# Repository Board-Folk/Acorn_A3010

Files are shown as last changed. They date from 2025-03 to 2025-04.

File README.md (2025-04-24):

# Reproduction A3010 PCB #

This repository contains the schematics and PCB layout for a reproduction
of the Acorn A3010 computer PCB - specifically the 194,003 issue 1.

Other variations of the board exist and may be included as separate designs
at a future date.

Where possible the board matches the location of components and routing of
traces.

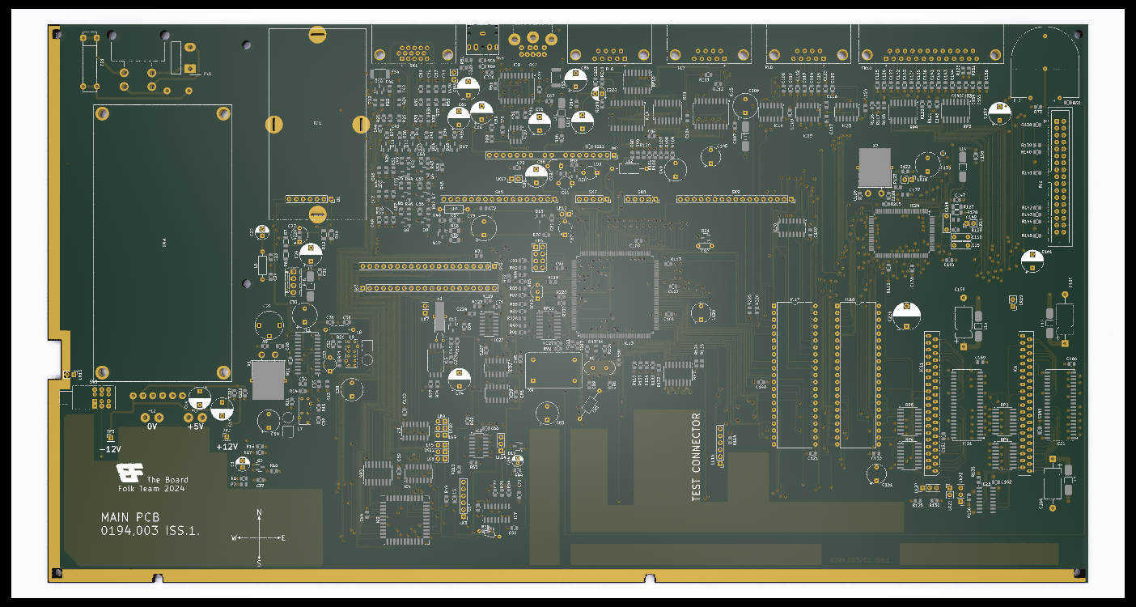
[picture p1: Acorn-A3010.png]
Render of PCB front


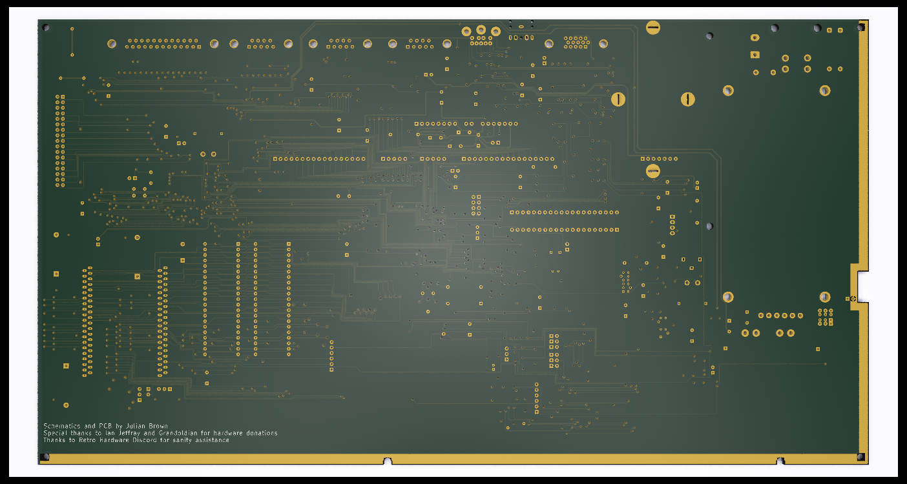
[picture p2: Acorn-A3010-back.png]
Render of PCB rear


## Progress ##

The schematics and PCB design are both complete. An initial fabrication run has
been completed and in the process of being tested. The first board is populated
and while it appears to be working over the post port, there is no apparent video
output

### Changes from first test build ###

The AC inputs to the Mean Well psu were reversed. This should not technically
Be a problem for the psi so can be considered cosmetic.

Footprint pad sizes have been enlarged for the LQFP and J-leg components to aid
With hand assembly.

### Known issues ###

The specified fuse rating for the AC input is inadequate for the Mean Well psu.
The initial power-up produces a spike in current that blows the fuse immediately,
it may prove more appropriate to remove the fuse and add protection to the outputs 

## Factory Fixes ##

The original boards include a number of fixes, these have been incorporated
into the design where possible.

## Variations From Standard ##

In a few places the board is non-standard to allow the use of modern, available
components, most notably the power supply area of the board. Instead of the 
original circuits the board is designed to accept a Mean Well unit that is 
both lighter and more efficient.

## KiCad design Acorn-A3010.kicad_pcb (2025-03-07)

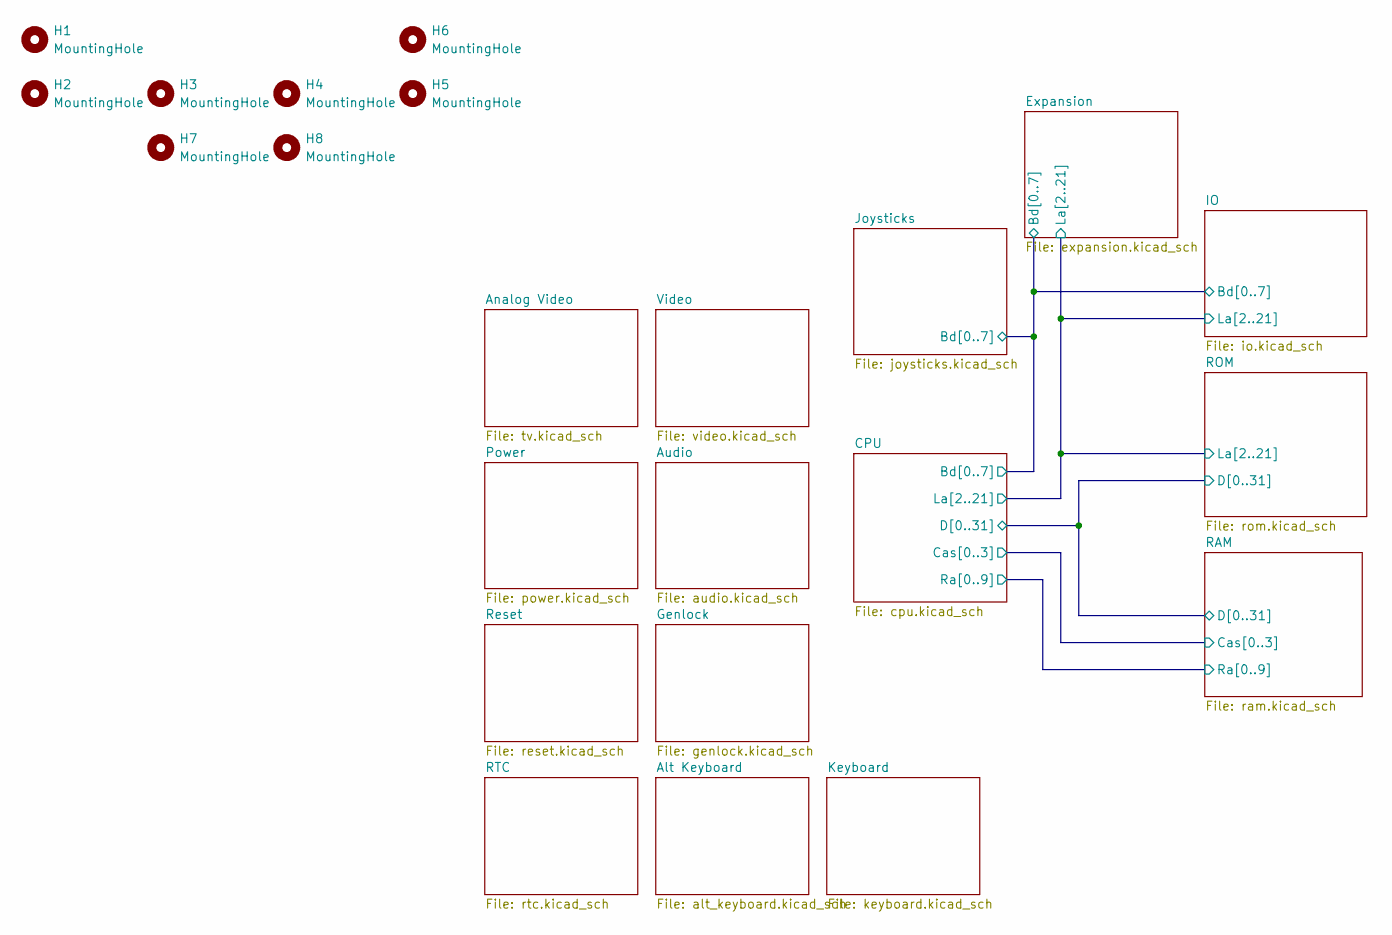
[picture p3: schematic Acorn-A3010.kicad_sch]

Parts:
H1, H2, H3, H4, H5, H6, H7, H8: MountingHole; MountingHole_3.2mm_M3

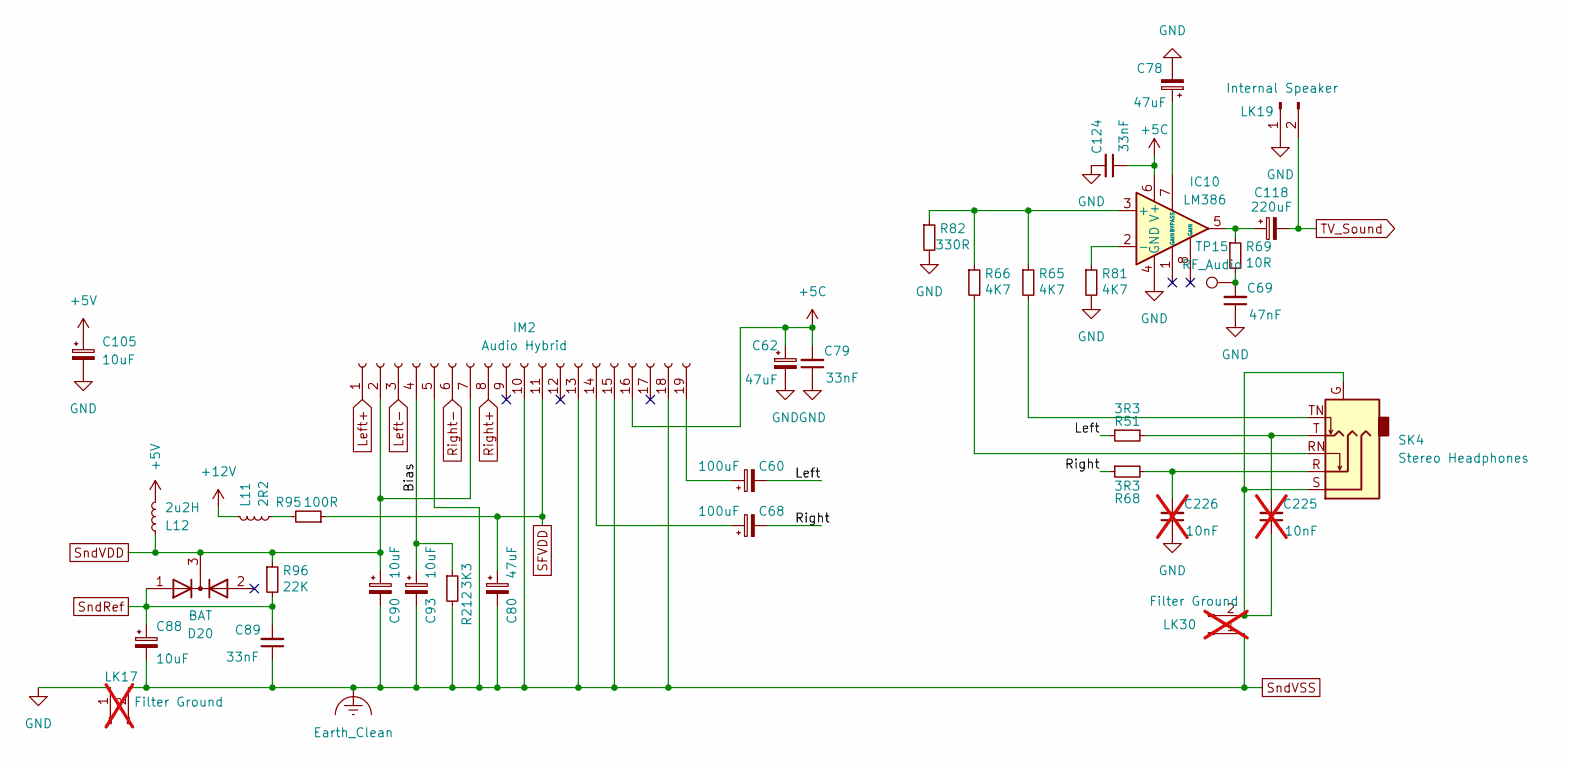
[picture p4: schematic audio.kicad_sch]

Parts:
C60, C68: 100uF; CP_Radial_D8.0mm_P5.00mm
C62, C78, C80: 47uF; CP_Radial_D8.0mm_P5.00mm
C69: 47nF; C_0805_2012Metric
C79, C89, C124: 33nF; C_0805_2012Metric
C88, C90, C93: 10uF; CP_Radial_Tantal_D4.5mm_P5.00mm
C105: 10uF; CP_Radial_Tantal_D7.0mm_P5.00mm
C118: 220uF; CP_Radial_D8.0mm_P5.00mm
C225, C226: 10nF; C_0805_2012Metric; not fitted
D20: BAT; SOT-23-3
IC10: LM386; SOIC-8_3.9x4.9mm_P1.27mm
IM2: Audio Hybrid; Audio_Hybrid
L11: 2R2; L_Acorn_8x3mm
L12: 2u2H; L_Axial_L7.0mm_D3.3mm_P12.70mm_Horizontal_Fastron_MICC
LK17, LK30: Filter Ground; PinHeader_1x02_P2.54mm_Vertical; not fitted
LK19: Internal Speaker; PinHeader_1x02_P2.54mm_Vertical
R51, R68: 3R3; R_0805_2012Metric
R65, R66, R81: 4K7; R_0805_2012Metric
R69: 10R; R_0805_2012Metric
R82: 330R; R_0805_2012Metric
R95: 100R; R_0805_2012Metric
R96: 22K; R_0805_2012Metric
R212: 3K3; R_0805_2012Metric
SK4: Stereo Headphones; Jack_3.5mm_CUI_SJ1-3525N_Horizontal
TP15: RF_Audio; TestPoint_Pad_D1.0mm

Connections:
+5C: C62.1, C79.2, C124.1, IC10.6 (V+), IM2.16; also elsewhere on the board
+5V: C105.1, L12.2; also elsewhere on the board
+12V: L11.1; also elsewhere on the board
/Audio/Bias: C93.1, IM2.4, R212.1
/Audio/Left: C60.2, R51.1
/Audio/Right: C68.2, R68.1
GND: C62.2, C69.1, C78.2, C79.1, C105.2, C124.2, C226.1, IC10.4 (GND), LK17.1, LK19.1, R81.2, R82.2; also elsewhere on the board
Left+: IM2.1; also elsewhere on the board
Left-: IM2.3; also elsewhere on the board
unnamed: C69.2, R69.2, TP15.1
unnamed: C118.1, IC10.5, R69.1
unnamed: C225.2, R51.2, SK4.T
unnamed: C226.2, R68.2, SK4.R
unnamed: IC10.3 (+), R65.1, R66.1, R82.1
unnamed: IC10.2 (-), R81.1
unnamed: C78.1, IC10.7 (BYPASS)
unnamed: C68.1, IM2.14
unnamed: C60.1, IM2.19
unnamed: L11.2, R95.2
unnamed: C225.1, LK30.2, SK4.G, SK4.S
unnamed: R65.2, SK4.TN
unnamed: R66.2, SK4.RN
Right+: IM2.8; also elsewhere on the board
Right-: IM2.6; also elsewhere on the board
SFVDD: C80.1, IM2.11, R95.1
SndRef: C88.1, C89.2, D20.1 (A), R96.2; also elsewhere on the board
SndVDD: C90.1, D20.3 (K), IM2.2, IM2.7, L12.1, R96.1; also elsewhere on the board
SndVSS: C80.2, C88.2, C89.1, C90.2, C93.2, IM2.5, IM2.10, IM2.13, IM2.15, IM2.18, LK17.2, LK30.1, R212.2; also elsewhere on the board
TV_Sound: C118.2, LK19.2; also elsewhere on the board

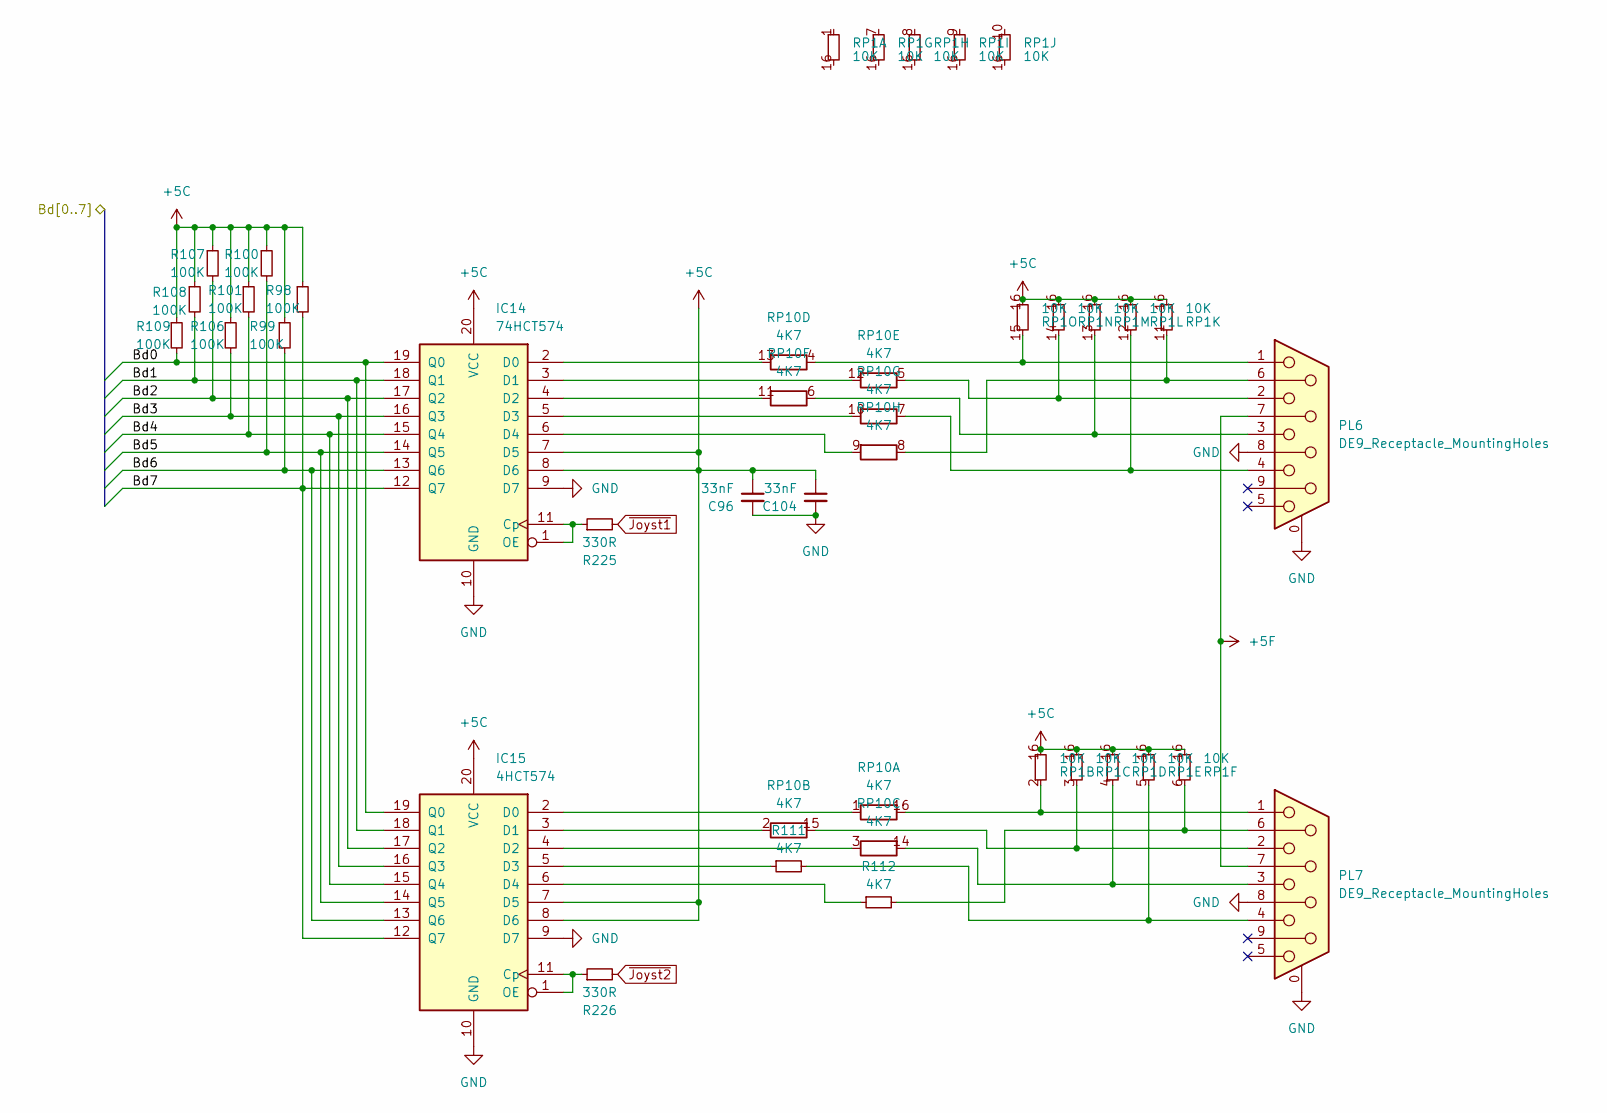
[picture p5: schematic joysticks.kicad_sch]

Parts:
C96, C104: 33nF; C_0805_2012Metric
IC14: 74HCT574; SOIC-20W_7.5x12.8mm_P1.27mm
IC15: 4HCT574; SOIC-20W_7.5x12.8mm_P1.27mm
PL6, PL7: DE9_Receptacle_MountingHoles; DSUB-9_Male_Horizontal_P2.77x2.84mm_EdgePinOffset9.90mm_Hou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
R98, R99, R100, R101, R106, R107, R108, R109: 100K; R_0805_2012Metric
R111, R112: 4K7; R_0805_2012Metric
R225, R226: 330R; R_0805_2012Metric
RP1: 10K; SOIC-16W_5.3x10.2mm_P1.27mm
RP10: 4K7; SOIC-16W_5.3x10.2mm_P1.27mm

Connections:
+5C: C96.1, C104.1, IC14.7 (D5), IC14.8 (D6), IC14.20 (VCC), IC15.7 (D5), IC15.8 (D6), IC15.20 (VCC), R98.1, R99.1, R100.1, R101.1, R106.1, R107.1, R108.1, R109.1, RP1.16; also elsewhere on the board
+5F: PL6.7, PL7.7; also elsewhere on the board
/CPU/Bd0: IC14.19 (Q0), IC15.19 (Q0), R109.2; also elsewhere on the board
/CPU/Bd1: IC14.18 (Q1), IC15.18 (Q1), R108.2; also elsewhere on the board
/CPU/Bd2: IC14.17 (Q2), IC15.17 (Q2), R107.2; also elsewhere on the board
/CPU/Bd3: IC14.16 (Q3), IC15.16 (Q3), R106.2; also elsewhere on the board
/CPU/Bd4: IC14.15 (Q4), IC15.15 (Q4), R101.2; also elsewhere on the board
/CPU/Bd5: IC14.14 (Q5), IC15.14 (Q5), R100.2; also elsewhere on the board
/CPU/Bd6: IC14.13 (Q6), IC15.13 (Q6), R99.2; also elsewhere on the board
/CPU/Bd7: IC14.12 (Q7), IC15.12 (Q7), R98.2; also elsewhere on the board
GND: C96.2, C104.2, IC14.9 (D7), IC14.10 (GND), IC15.9 (D7), IC15.10 (GND), PL6.0 (PAD), PL6.8, PL7.0 (PAD), PL7.8; also elsewhere on the board
unnamed: IC14.1 (OE), IC14.11 (Cp), R225.1
unnamed: IC14.2 (D0), RP10.13 (R4.2)
unnamed: IC14.3 (D1), RP10.12 (R5.2)
unnamed: IC14.4 (D2), RP10.11 (R6.2)
unnamed: IC14.5 (D3), RP10.10 (R7.2)
unnamed: IC14.6 (D4), RP10.9 (R8.2)
unnamed: IC15.1 (OE), IC15.11 (Cp), R226.1
unnamed: IC15.2 (D0), RP10.1 (R1.1)
unnamed: IC15.3 (D1), RP10.2 (R2.1)
unnamed: IC15.4 (D2), RP10.3 (R3.1)
unnamed: IC15.5 (D3), R111.1
unnamed: IC15.6 (D4), R112.1
unnamed: PL7.4, R111.2, RP1.5
unnamed: PL7.6, R112.2, RP1.6
unnamed: PL7.1, RP1.2, RP10.16 (R1.2)
unnamed: PL7.2, RP1.3, RP10.15 (R2.2)
unnamed: PL7.3, RP1.4, RP10.14 (R3.2)
unnamed: PL6.1, RP1.15, RP10.4 (R4.1)
unnamed: PL6.2, RP1.14, RP10.5 (R5.1)
unnamed: PL6.3, RP1.13, RP10.6 (R6.1)
unnamed: PL6.4, RP1.12, RP10.7 (R7.1)
unnamed: PL6.6, RP1.11, RP10.8 (R8.1)
~Joyst1: R225.2; also elsewhere on the board
~Joyst2: R226.2; also elsewhere on the board

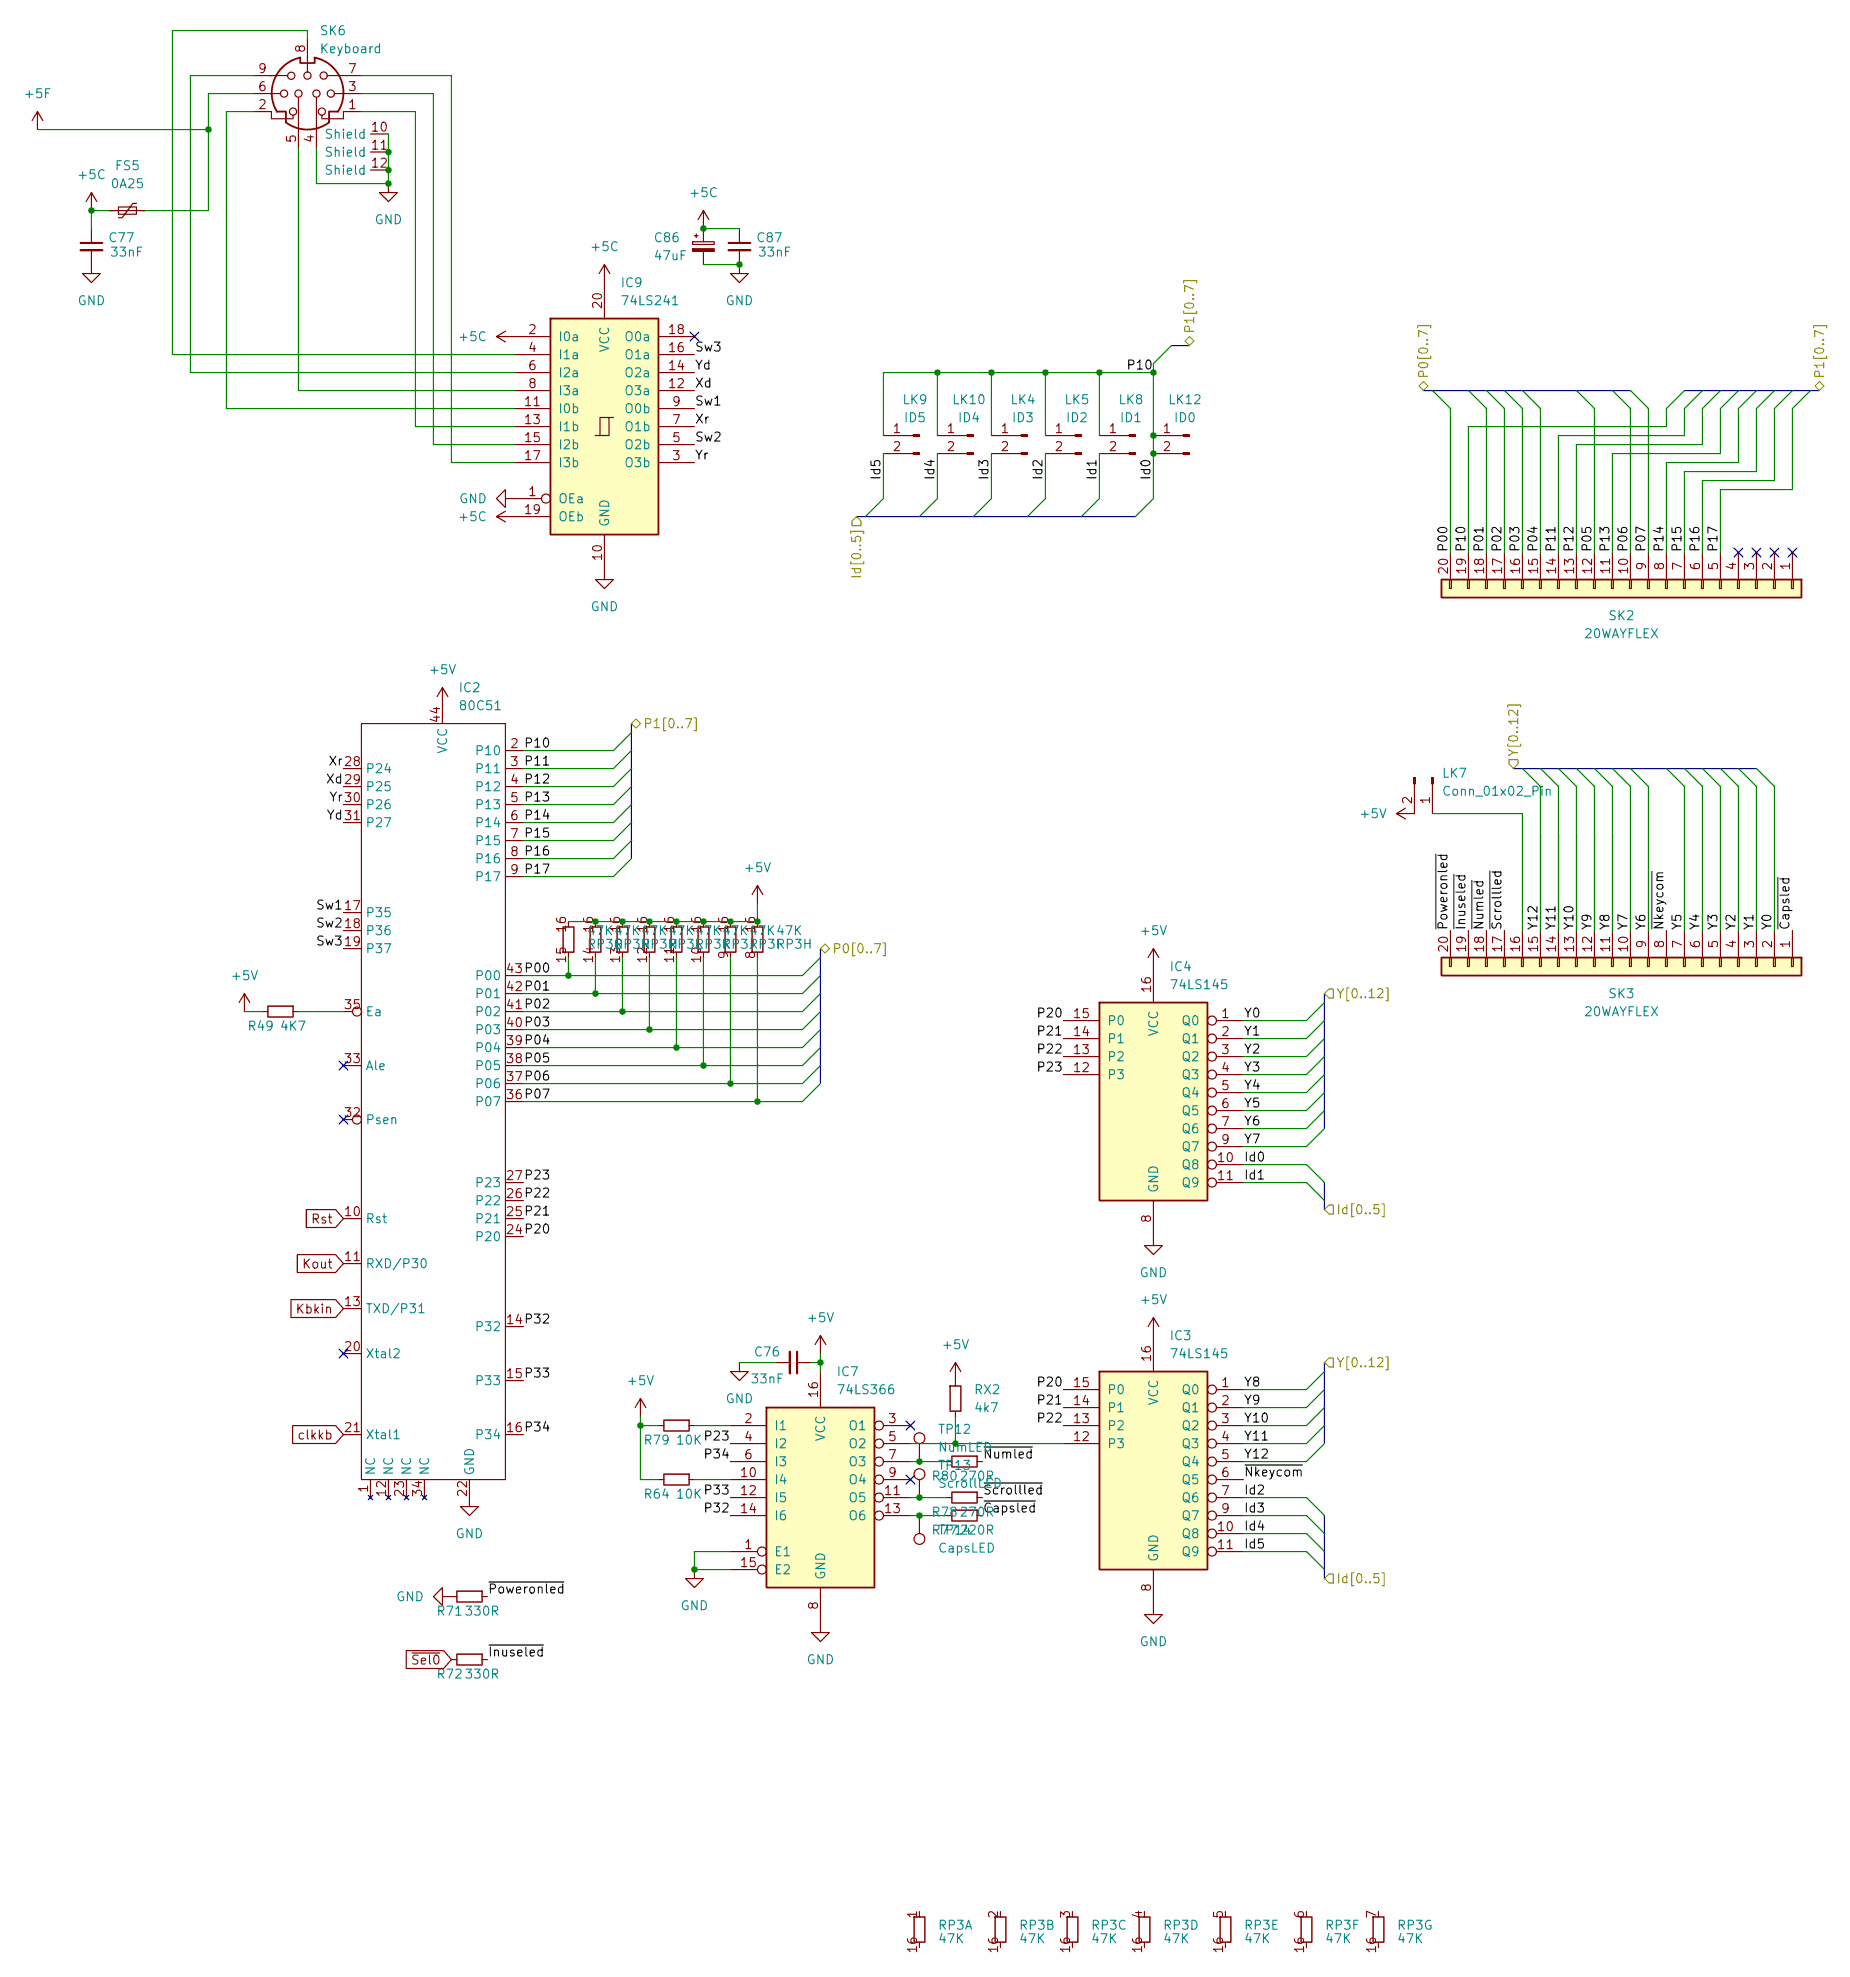
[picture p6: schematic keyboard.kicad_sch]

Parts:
C76, C77, C87: 33nF; C_0805_2012Metric
C86: 47uF; CP_Radial_D8.0mm_P5.00mm
FS5: 0A25; Fuse_2512_6332Metric
IC2: 80C51; PLCC-44
IC3, IC4: 74LS145; SOIC-16_3.9x9.9mm_P1.27mm
IC7: 74LS366; SOIC-16_3.9x9.9mm_P1.27mm
IC9: 74LS241; SOIC-20W_7.5x12.8mm_P1.27mm
LK4: ID3; Link
LK5: ID2; Link
LK7: Conn_01x02_Pin; PinHeader_1x02_P2.54mm_Vertical
LK8: ID1; Link
LK9: ID5; Link
LK10: ID4; Link
LK12: ID0; Link
R49: 4K7; R_0805_2012Metric
R64, R79: 10K; R_0805_2012Metric
R71, R72: 330R; R_0805_2012Metric
R77: 220R; R_0805_2012Metric
R78, R80: 270R; R_0805_2012Metric
RP3: 47K; SOIC-16W_5.3x10.2mm_P1.27mm
RX2: 4k7; R_Axial_DIN0204_L3.6mm_D1.6mm_P7.62mm_Horizontal
SK2, SK3: 20WAYFLEX; PinHeader_1x20_P2.54mm_Vertical
SK6: Keyboard; Mini-DIN_9
TP12: NumLED; TestPoint_Pad_D1.0mm
TP13: ScrollLED; TestPoint_Pad_D1.0mm
TP14: CapsLED; TestPoint_Pad_D1.0mm

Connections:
+5C: C77.1, C86.1, C87.1, FS5.1, IC9.2 (I0a), IC9.19 (OEb), IC9.20 (VCC); also elsewhere on the board
+5F: FS5.2, SK6.6; also elsewhere on the board
+5V: C76.1, IC2.44 (VCC), IC3.16 (VCC), IC4.16 (VCC), IC7.16 (VCC), LK7.2, R49.2, R64.2, R79.2, RP3.16, RX2.1; also elsewhere on the board
/Keyboard/Id1: IC4.11 (Q9), LK8.2
/Keyboard/Id2: IC3.7 (Q6), LK5.2
/Keyboard/Id3: IC3.9 (Q7), LK4.2
/Keyboard/Id4: IC3.10 (Q8), LK10.2
/Keyboard/Id5: IC3.11 (Q9), LK9.2
/Keyboard/P00: IC2.43 (P00), RP3.15, SK2.20
/Keyboard/P01: IC2.42 (P01), RP3.14, SK2.18
/Keyboard/P02: IC2.41 (P02), RP3.13, SK2.17
/Keyboard/P03: IC2.40 (P03), RP3.12, SK2.16
/Keyboard/P04: IC2.39 (P04), RP3.11, SK2.15
/Keyboard/P05: IC2.38 (P05), RP3.10, SK2.12
/Keyboard/P06: IC2.37 (P06), RP3.9, SK2.10
/Keyboard/P07: IC2.36 (P07), RP3.8, SK2.9
/Keyboard/P10: IC2.2 (P10), IC4.10 (Q8), LK4.1, LK5.1, LK8.1, LK9.1, LK10.1, LK12.1, LK12.2, SK2.19
/Keyboard/P11: IC2.3 (P11), SK2.14
/Keyboard/P12: IC2.4 (P12), SK2.13
/Keyboard/P13: IC2.5 (P13), SK2.11
/Keyboard/P14: IC2.6 (P14), SK2.8
/Keyboard/P15: IC2.7 (P15), SK2.7
/Keyboard/P16: IC2.8 (P16), SK2.6
/Keyboard/P17: IC2.9 (P17), SK2.5
/Keyboard/P20: IC2.24 (P20), IC3.15 (P0), IC4.15 (P0)
/Keyboard/P21: IC2.25 (P21), IC3.14 (P1), IC4.14 (P1)
/Keyboard/P22: IC2.26 (P22), IC3.13 (P2), IC4.13 (P2)
/Keyboard/P23: IC2.27 (P23), IC4.12 (P3), IC7.4 (I2)
/Keyboard/P32: IC2.14 (P32), IC7.14 (I6)
/Keyboard/P33: IC2.15 (P33), IC7.12 (I5)
/Keyboard/P34: IC2.16 (P34), IC7.6 (I3)
/Keyboard/Sw1: IC2.17 (P35), IC9.9 (O0b)
/Keyboard/Sw2: IC2.18 (P36), IC9.5 (O2b)
/Keyboard/Sw3: IC2.19 (P37), IC9.16 (O1a)
/Keyboard/Xd: IC2.29 (P25), IC9.12 (O3a)
/Keyboard/Xr: IC2.28 (P24), IC9.7 (O1b)
/Keyboard/Y0: IC4.1 (Q0), SK3.2
/Keyboard/Y1: IC4.2 (Q1), SK3.3
/Keyboard/Y2: IC4.3 (Q2), SK3.4
/Keyboard/Y3: IC4.4 (Q3), SK3.5
/Keyboard/Y4: IC4.5 (Q4), SK3.6
/Keyboard/Y5: IC4.6 (Q5), SK3.7
/Keyboard/Y6: IC4.7 (Q6), SK3.9
/Keyboard/Y7: IC4.9 (Q7), SK3.10
/Keyboard/Y8: IC3.1 (Q0), SK3.11
/Keyboard/Y9: IC3.2 (Q1), SK3.12
/Keyboard/Y10: IC3.3 (Q2), SK3.13
/Keyboard/Y11: IC3.4 (Q3), SK3.14
/Keyboard/Y12: IC3.5 (Q4), SK3.15
/Keyboard/Yd: IC2.31 (P27), IC9.14 (O2a)
/Keyboard/Yr: IC2.30 (P26), IC9.3 (O3b)
/Keyboard/~Capsled: R77.1, SK3.1
/Keyboard/~Inuseled: R72.1, SK3.19
/Keyboard/~Nkeycom: IC3.6 (Q5), SK3.8
/Keyboard/~Numled: R80.1, SK3.18
/Keyboard/~Poweronled: R71.1, SK3.20
/Keyboard/~Scrollled: R78.1, SK3.17
GND: C76.2, C77.2, C86.2, C87.2, IC2.22 (GND), IC3.8 (GND), IC4.8 (GND), IC7.1 (E1), IC7.8 (GND), IC7.15 (E2), IC9.1 (OEa), IC9.10 (GND), R71.2, SK6.4, SK6.10 (Shield), SK6.11 (Shield), SK6.12 (Shield); also elsewhere on the board
Kbkin: IC2.13 (TXD/P31); also elsewhere on the board
Kout: IC2.11 (RXD/P30); also elsewhere on the board
unnamed: IC2.35 (Ea), R49.1
unnamed: IC3.12 (P3), IC7.5 (O2), RX2.2
unnamed: IC7.2 (I1), R79.1
unnamed: IC7.10 (I4), R64.1
unnamed: IC7.7 (O3), R80.2, TP12.1
unnamed: IC7.11 (O5), R78.2, TP13.1
unnamed: IC7.13 (O6), R77.2, TP14.1
unnamed: IC9.11 (I0b), SK6.2
unnamed: IC9.4 (I1a), SK6.8
unnamed: IC9.13 (I1b), SK6.1
unnamed: IC9.6 (I2a), SK6.9
unnamed: IC9.15 (I2b), SK6.3
unnamed: IC9.8 (I3a), SK6.5
unnamed: IC9.17 (I3b), SK6.7
unnamed: LK7.1, SK3.16
Rst: IC2.10 (Rst); also elsewhere on the board
clkkb: IC2.21 (Xtal1); also elsewhere on the board
~Sel0: R72.2; also elsewhere on the board

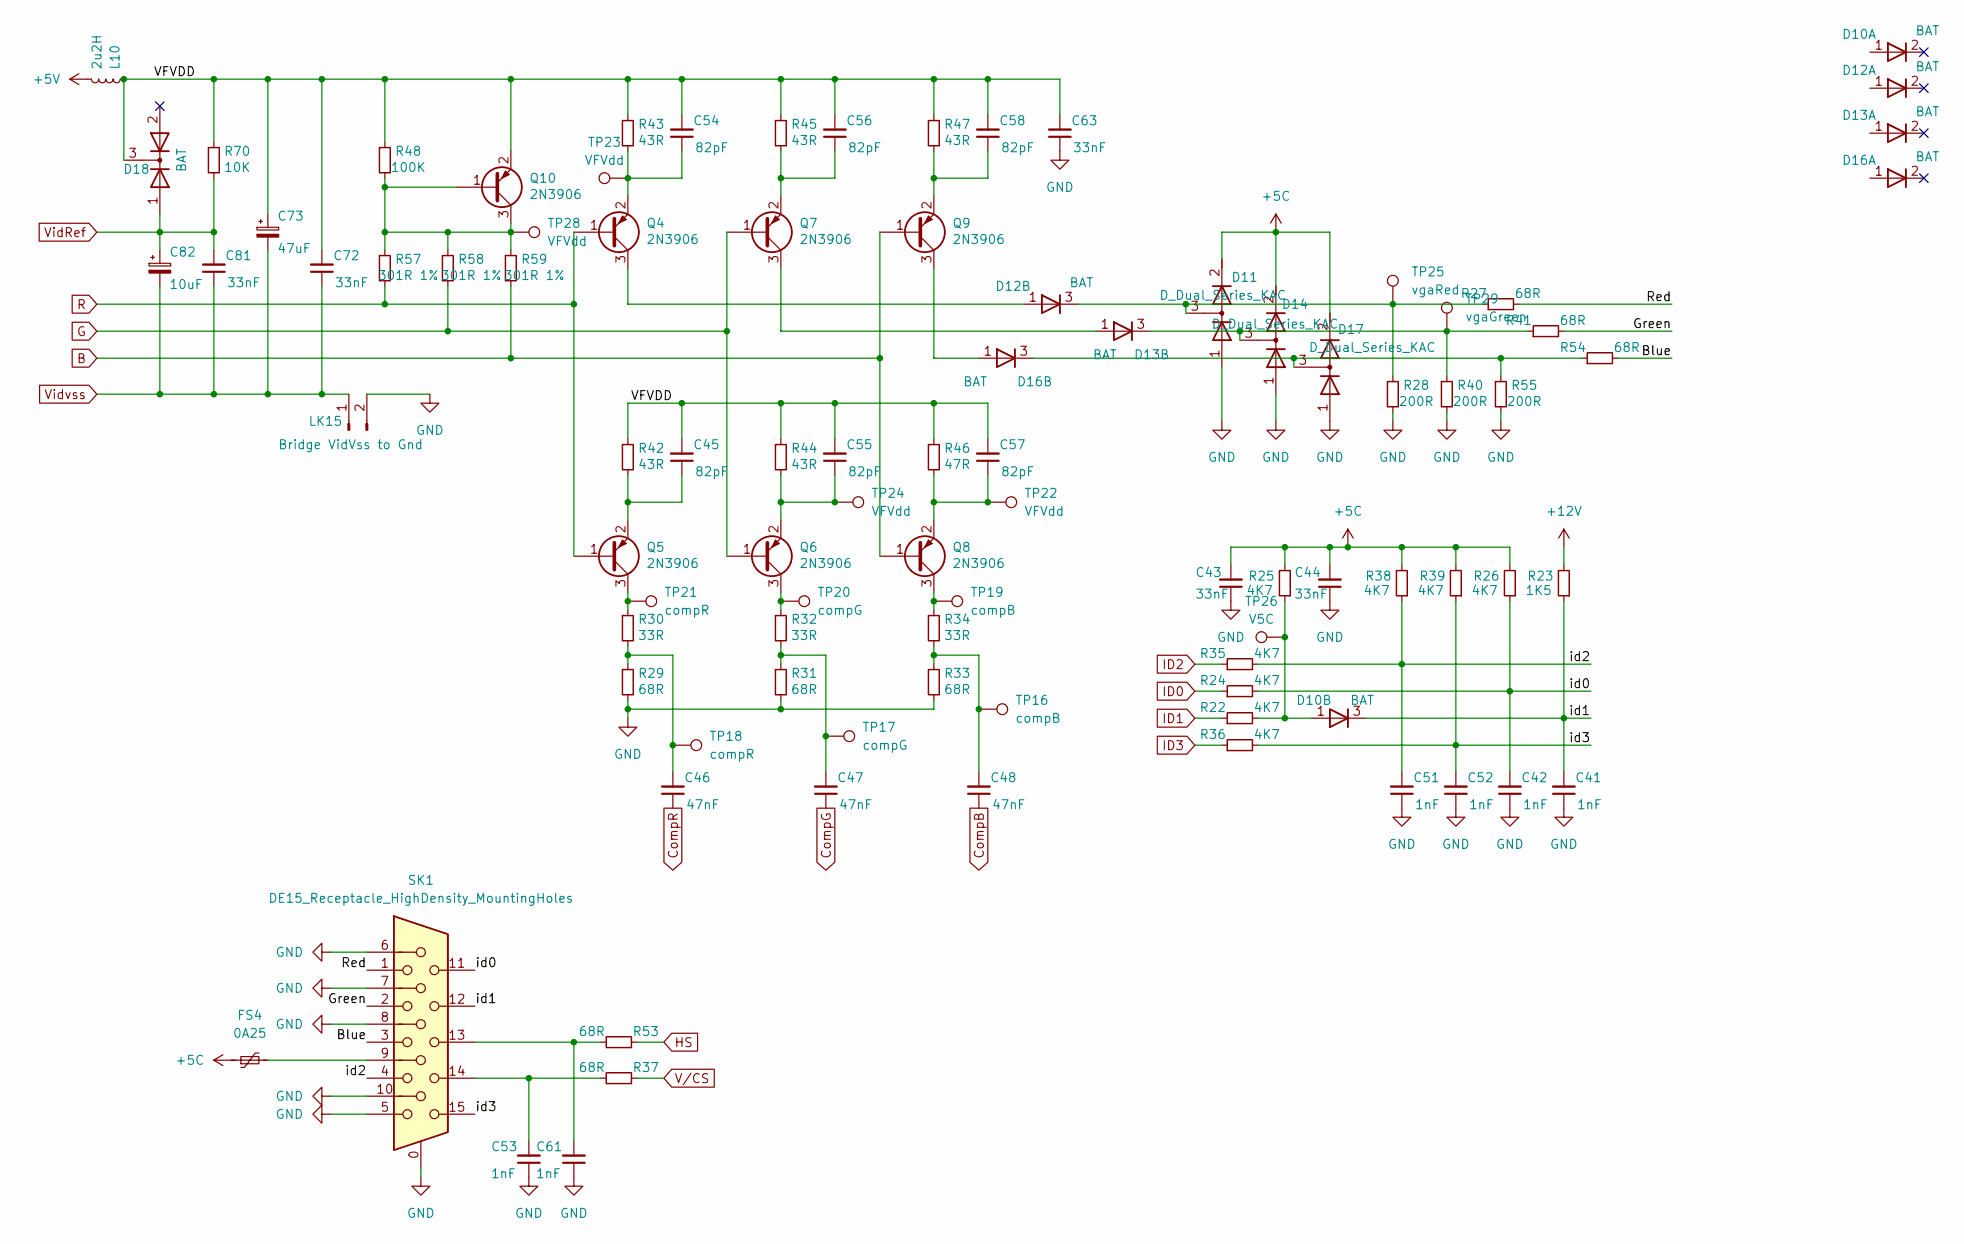
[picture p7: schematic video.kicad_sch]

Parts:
C41, C42, C51, C52, C53, C61: 1nF; C_0805_2012Metric
C43, C44, C63, C72, C81: 33nF; C_0805_2012Metric
C45, C54, C55, C56, C57, C58: 82pF; C_0805_2012Metric
C46, C47, C48: 47nF; C_0805_2012Metric
C73: 47uF; CP_Radial_Tantal_D9.0mm_P5.00mm
C82: 10uF; CP_Radial_Tantal_D4.5mm_P5.00mm
D10, D12, D13, D16, D18: BAT; SOT-23-3
D11, D14, D17: D_Dual_Series_KAC; SOT-23-3
FS4: 0A25; Fuse_2512_6332Metric
L10: 2u2H; L_Axial_L6.6mm_D2.7mm_P10.16mm_Horizontal_Vishay_IM-2
LK15: Bridge VidVss to Gnd; PinHeader_1x02_P2.54mm_Vertical
Q4, Q5, Q6, Q7, Q8, Q9, Q10: 2N3906; SOT-23-3
R22, R24, R25, R26, R35, R36, R38, R39: 4K7; R_0805_2012Metric
R23: 1K5; R_0805_2012Metric
R27, R29, R31, R33, R37, R41, R53, R54: 68R; R_0805_2012Metric
R28, R40, R55: 200R; R_0805_2012Metric
R30, R32, R34: 33R; R_0805_2012Metric
R42, R43, R44, R45, R47: 43R; R_0805_2012Metric
R46: 47R; R_0805_2012Metric
R48: 100K; R_0805_2012Metric
R57, R58, R59: 301R 1%; R_1206_3216Metric
R70: 10K; R_0805_2012Metric
SK1: DE15_Receptacle_HighDensity_MountingHoles; DSUB-15-HD_Female_Horizontal_P2.29x1.98mm_EdgePinOffset8.35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
TP16, TP19: compB; TestPoint_Pad_D1.0mm
TP17, TP20: compG; TestPoint_Pad_D1.0mm
TP18, TP21: compR; TestPoint_Pad_D1.0mm
TP22, TP23, TP24, TP28: VFVdd; TestPoint_Pad_D1.0mm
TP25: vgaRed; TestPoint_Pad_D1.0mm
TP26: V5C; TestPoint_Pad_D1.0mm
TP29: vgaGreen; TestPoint_Pad_D1.0mm

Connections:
+5C: C43.2, C44.2, D11.2 (K), D14.2 (K), D17.2 (K), FS4.1, R25.2, R26.2, R38.2, R39.2; also elsewhere on the board
+5V: L10.2; also elsewhere on the board
+12V: R23.2; also elsewhere on the board
/Video/Blue: R54.2, SK1.3
/Video/Green: R41.2, SK1.2
/Video/Red: R27.2, SK1.1
/Video/VFVDD: C45.2, C54.2, C55.2, C56.2, C57.2, C58.2, C63.2, C72.2, C73.1, D18.3 (K), L10.1, Q10.2 (E), R42.1, R43.1, R44.1, R45.1, R46.1, R47.1, R48.1, R70.1
/Video/id0: C42.2, R24.2, R26.1, SK1.11
/Video/id1: C41.2, D10.3 (K), R23.1, SK1.12
/Video/id2: C51.2, R35.2, R38.1, SK1.4
/Video/id3: C52.2, R36.2, R39.1, SK1.15
B: Q8.1 (B), Q9.1 (B), R59.2; also elsewhere on the board
CompB: C48.1; also elsewhere on the board
CompG: C47.1; also elsewhere on the board
CompR: C46.1; also elsewhere on the board
G: Q6.1 (B), Q7.1 (B), R58.2; also elsewhere on the board
GND: C41.1, C42.1, C43.1, C44.1, C51.1, C52.1, C53.1, C61.1, C63.1, D11.1 (A), D14.1 (A), D17.1 (A), LK15.2, R28.2, R29.2, R31.2, R33.2, R40.2, R55.2, SK1.0, SK1.5, SK1.6, SK1.7, SK1.8, SK1.10; also elsewhere on the board
HS: R53.1; also elsewhere on the board
ID0: R24.1; also elsewhere on the board
ID1: R22.1; also elsewhere on the board
ID2: R35.1; also elsewhere on the board
ID3: R36.1; also elsewhere on the board
unnamed: C46.2, R29.1, R30.2, TP18.1
unnamed: C47.2, R31.1, R32.2, TP17.1
unnamed: C48.2, R33.1, R34.2, TP16.1
unnamed: C53.2, R37.2, SK1.14
unnamed: C61.2, R53.2, SK1.13
unnamed: D10.1 (A), R22.2, R25.1, TP26.1
unnamed: D11.3 (common), D12.3 (K), R27.1, R28.1, TP25.1
unnamed: D12.1 (A), Q4.3 (C)
unnamed: D13.1 (A), Q7.3 (C)
unnamed: D13.3 (K), D14.3 (common), R40.1, R41.1, TP29.1
unnamed: D16.1 (A), Q9.3 (C)
unnamed: D16.3 (K), D17.3 (common), R54.1, R55.1
unnamed: FS4.2, SK1.9
unnamed: C54.1, Q4.2 (E), R43.2, TP23.1
unnamed: Q5.3 (C), R30.1, TP21.1
unnamed: C45.1, Q5.2 (E), R42.2
unnamed: Q6.3 (C), R32.1, TP20.1
unnamed: C55.1, Q6.2 (E), R44.2, TP24.1
unnamed: C56.1, Q7.2 (E), R45.2
unnamed: Q8.3 (C), R34.1, TP19.1
unnamed: C57.1, Q8.2 (E), R46.2, TP22.1
unnamed: C58.1, Q9.2 (E), R47.2
unnamed: Q10.1 (B), Q10.3 (C), R48.2, R57.1, R58.1, R59.1, TP28.1
R: Q4.1 (B), Q5.1 (B), R57.2; also elsewhere on the board
VidRef: C81.2, C82.1, D18.1 (A), R70.2; also elsewhere on the board
Vidvss: C72.1, C73.2, C81.1, C82.2, LK15.1; also elsewhere on the board
V/CS: R37.1; also elsewhere on the board

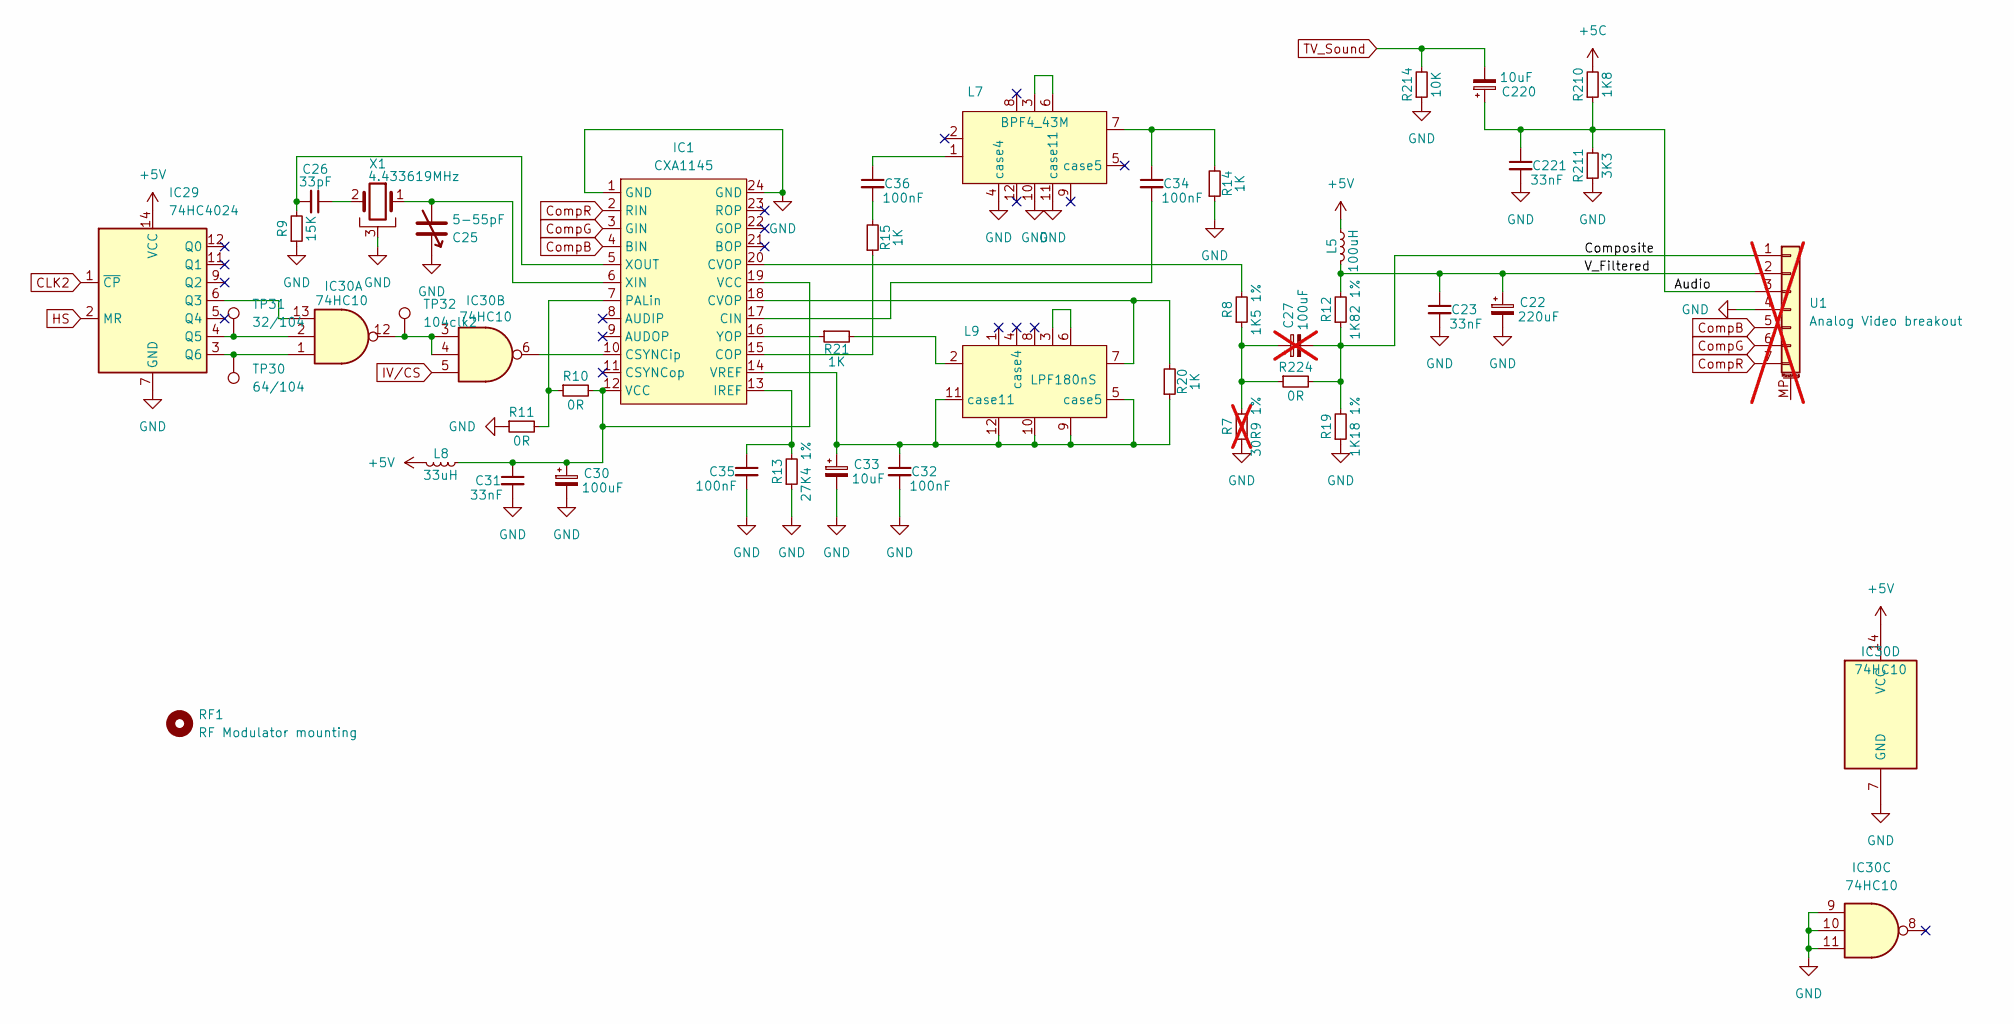
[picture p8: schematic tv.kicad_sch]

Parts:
C22: 220uF; CP_Radial_D5.0mm_P2.50mm
C23, C31, C221: 33nF; C_0805_2012Metric
C25: 5-55pF; Trim_Capacitor
C26: 33pF; C_0805_2012Metric
C27: 100uF; CP_Radial_Tantal_D6.0mm_P5.00mm; not fitted
C30: 100uF; CP_Radial_Tantal_D9.0mm_P5.00mm
C32, C34, C35, C36: 100nF; C_0805_2012Metric
C33: 10uF; CP_Radial_Tantal_D4.5mm_P5.00mm
C220: 10uF; CP_Radial_D5.0mm_P2.50mm
IC1: CXA1145; SOJ-24_7.62x15.875mm_P1.27mm
IC29: 74HC4024; SOIC-14_3.9x8.7mm_P1.27mm
IC30: 74HC10; SOIC-14_3.9x8.7mm_P1.27mm
L5: 100uH; L_Axial_L6.6mm_D2.7mm_P10.16mm_Horizontal_Vishay_IM-2
L7: BPF4_43M
L8: 33uH; L_Axial_L6.6mm_D2.7mm_P10.16mm_Horizontal_Vishay_IM-2
L9: LPF180nS
R7: 30R9 1%; R_1206_3216Metric; not fitted
R8: 1K5 1%; R_1206_3216Metric
R9: 15K; R_0805_2012Metric
R10, R11, R224: 0R; R_0805_2012Metric
R12: 1K82 1%; R_1206_3216Metric
R13: 27K4 1%; R_0805_2012Metric
R14, R15, R20, R21: 1K; R_0805_2012Metric
R19: 1K18 1%; R_1206_3216Metric
R210: 1K8; R_0805_2012Metric
R211: 3K3; R_0805_2012Metric
R214: 10K; R_0805_2012Metric
RF1: RF Modulator mounting; Rf Modulator
TP30: 64/104; TestPoint_Pad_D1.0mm
TP31: 32/104; TestPoint_Pad_D1.0mm
TP32: 104clk2; TestPoint_Pad_D1.0mm
U1: Analog Video breakout; PinSocket_1x07_P2.54mm_Vertical; not fitted
X1: 4.433619MHz; Crystal_HC50_Horizontal_1EP_style2

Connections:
+5C: R210.2; also elsewhere on the board
+5V: IC29.14 (VCC), IC30.14 (VCC), L5.1, L8.2; also elsewhere on the board
/Analog Video/Audio: C220.1, C221.1, R210.1, R211.2, U1.3
/Analog Video/Composite: C27.2, R12.1, R19.2, R224.2, U1.1
/Analog Video/V_Filtered: C22.1, C23.1, L5.2, R12.2, U1.2
CLK2: IC29.1 (~CP); also elsewhere on the board
CompB: IC1.4 (BIN), U1.5; also elsewhere on the board
CompG: IC1.3 (GIN), U1.6; also elsewhere on the board
CompR: IC1.2 (RIN), U1.7; also elsewhere on the board
GND: C22.2, C23.2, C25.1, C30.2, C31.2, C32.2, C33.2, C35.2, C221.2, IC1.1 (GND), IC1.24 (GND), IC29.7 (GND), IC30.7 (GND), IC30.9, IC30.10, IC30.11, L7.4 (case4), L7.10, L7.11 (case11), R7.1, R9.1, R11.1, R13.1, R14.1, R19.1, R211.1, R214.1, U1.4, X1.3; also elsewhere on the board
HS: IC29.2 (MR); also elsewhere on the board
IV/CS: IC30.5; also elsewhere on the board
unnamed: C26.1, X1.2
unnamed: C27.1, R7.2, R8.1, R224.1
unnamed: C30.1, C31.1, IC1.12 (VCC), IC1.19 (VCC), L8.1, R10.2
unnamed: C34.1, L7.7, R14.2
unnamed: C36.1, L7.1
unnamed: C36.2, R15.2
unnamed: C34.2, IC1.17 (CIN)
unnamed: IC1.15 (COP), R15.1
unnamed: IC1.10 (CSYNCip), IC30.6
unnamed: IC1.18 (CVOP), L9.7, R20.2
unnamed: IC1.20 (CVOP), R8.2
unnamed: C35.1, IC1.13 (IREF), R13.2
unnamed: IC1.7 (PALin), R10.1, R11.2
unnamed: C32.1, C33.1, IC1.14 (VREF), L9.5 (case5), L9.9, L9.10, L9.11 (case11), L9.12, R20.1
unnamed: C25.2, IC1.6 (XIN), X1.1
unnamed: C26.2, IC1.5 (XOUT), R9.2
unnamed: IC1.16 (YOP), R21.1
unnamed: IC29.6 (Q3), IC30.13
unnamed: IC29.4 (Q5), IC30.2, TP31.1
unnamed: IC29.3 (Q6), IC30.1, TP30.1
unnamed: IC30.3, IC30.4, IC30.12, TP32.1
unnamed: L7.3, L7.6
unnamed: L9.2, R21.2
unnamed: L9.3, L9.6
TV_Sound: C220.2, R214.2; also elsewhere on the board

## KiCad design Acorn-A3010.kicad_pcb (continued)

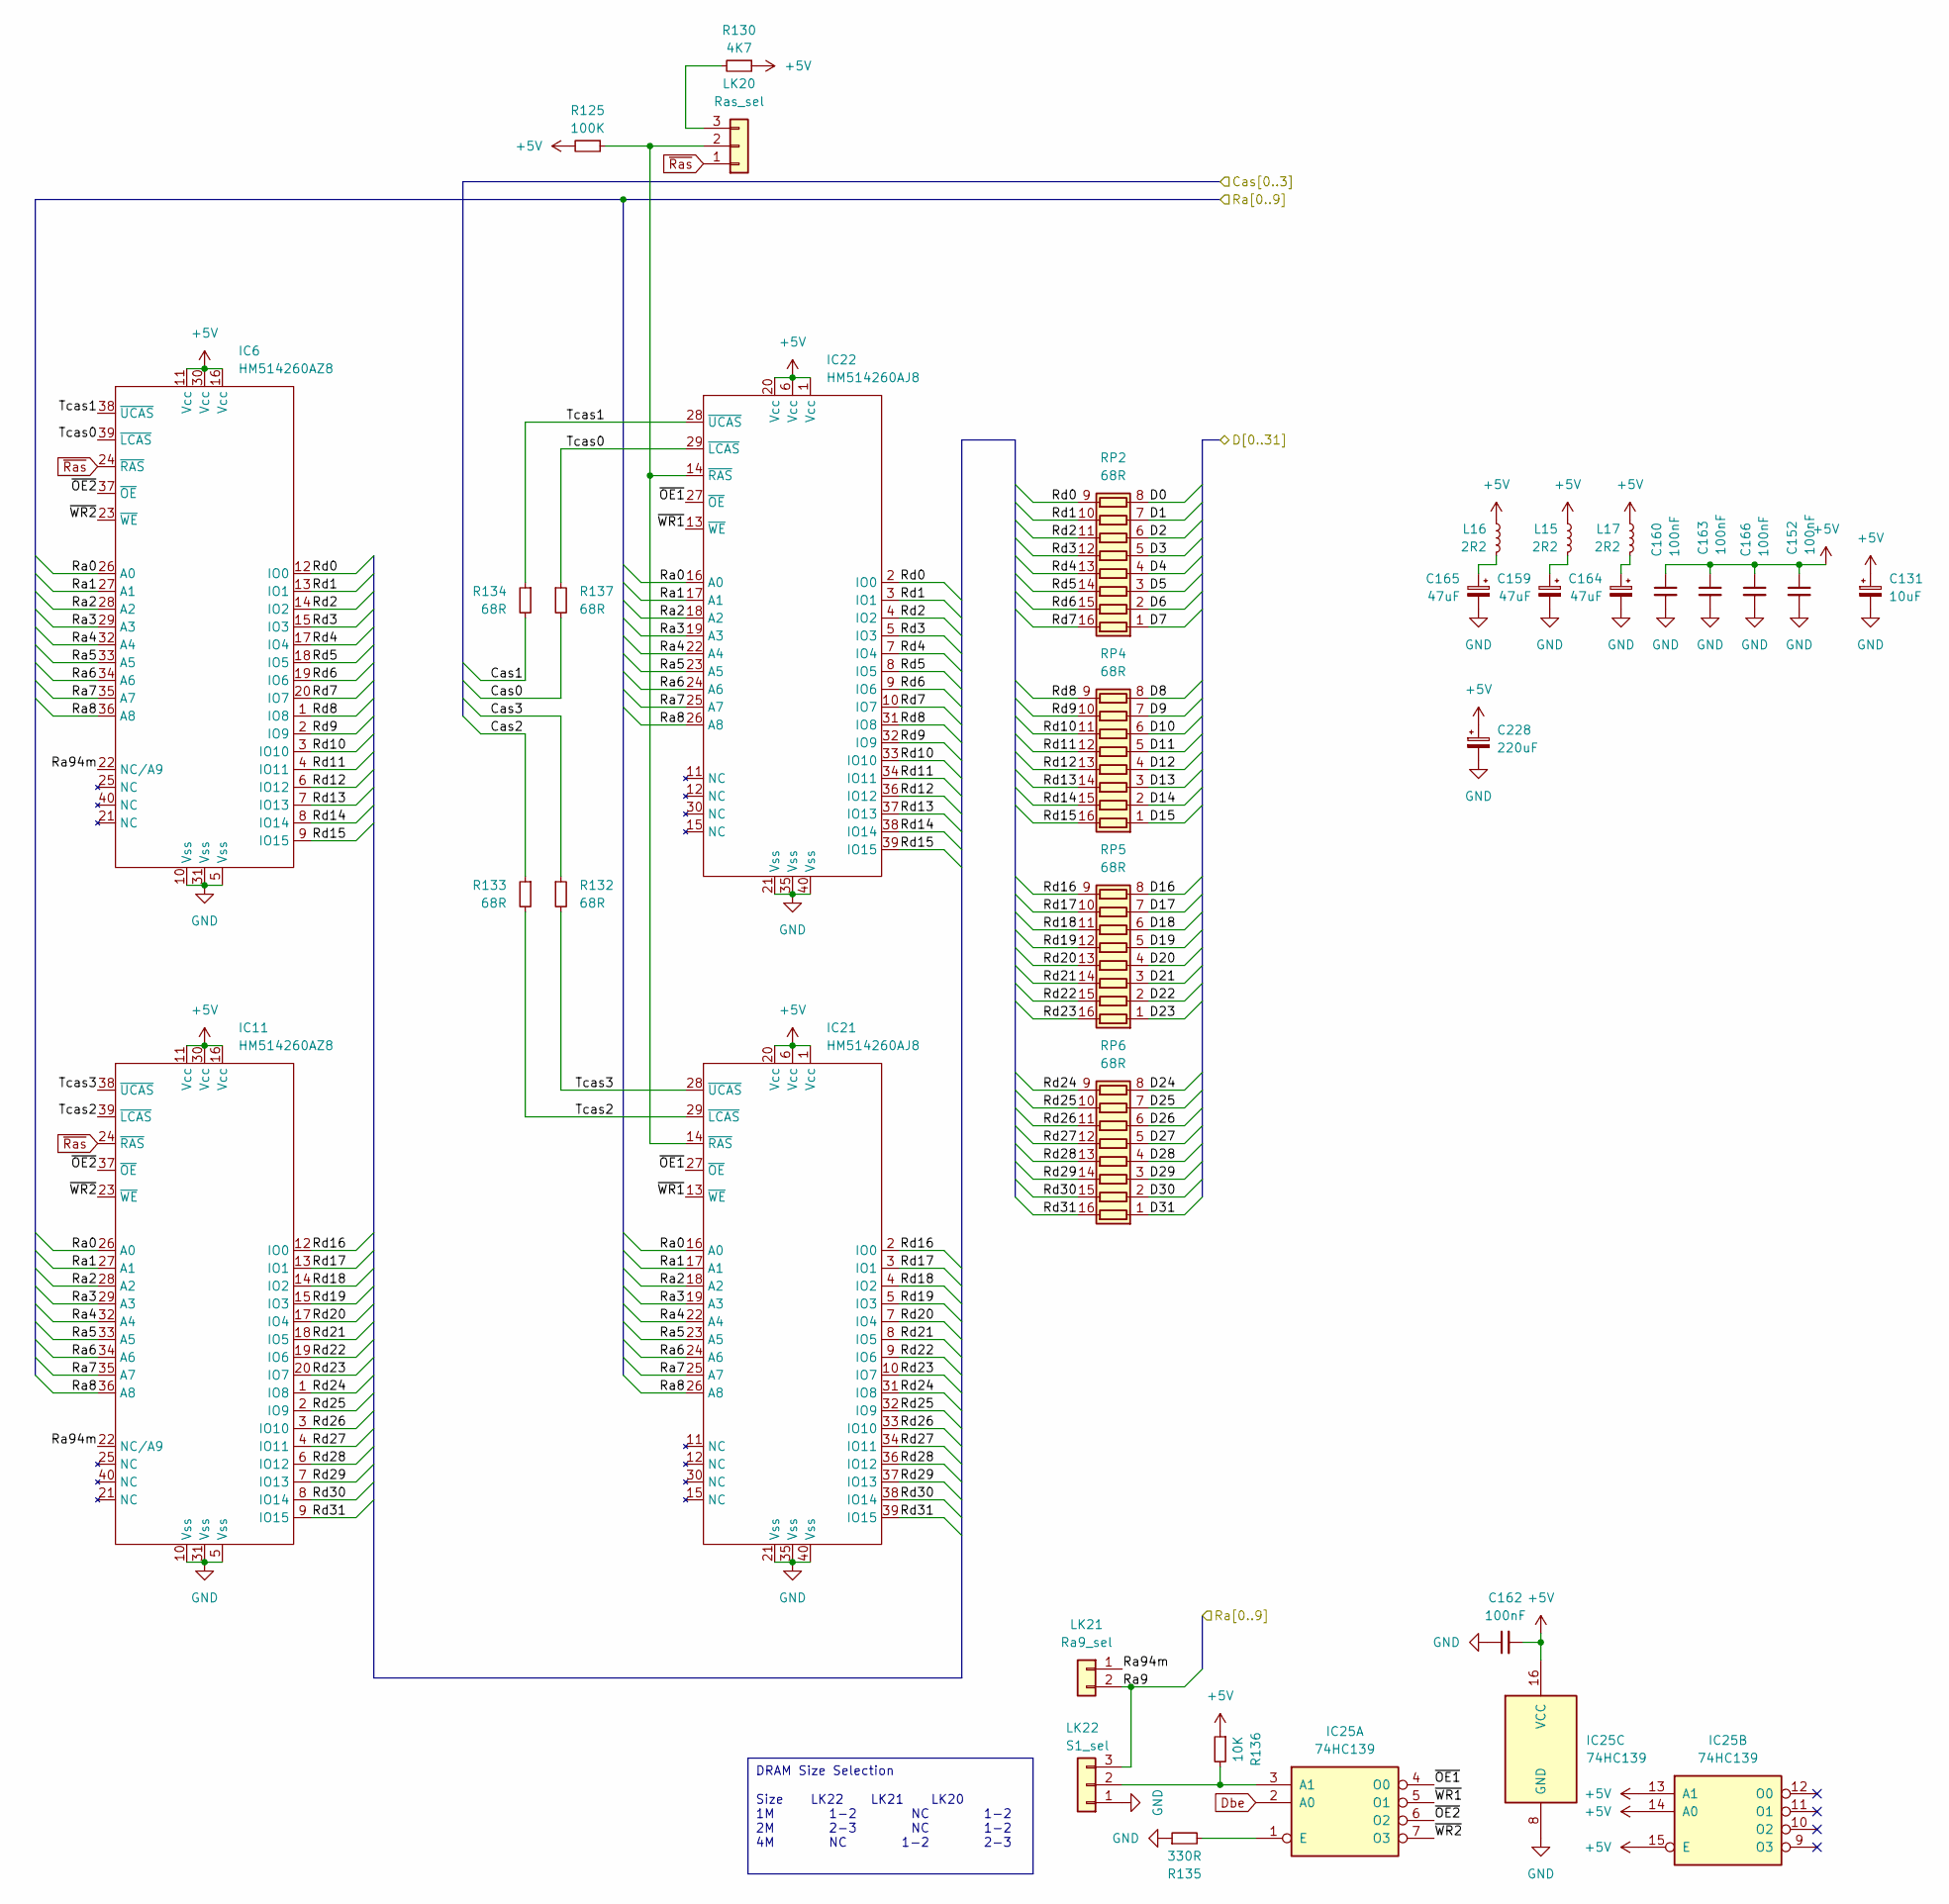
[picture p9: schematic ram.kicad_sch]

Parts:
C131: 10uF; CP_Radial_Tantal_D7.0mm_P5.00mm
C152, C160, C162, C163, C166: 100nF; C_0805_2012Metric
C159, C164, C165: 47uF; CP_Axial_L11.0mm_D6.0mm_P18.00mm_Horizontal
C228: 220uF; CP_Radial_D10.0mm_P7.50mm
IC6, IC11: HM514260AZ8; ZIP-40
IC21, IC22: HM514260AJ8; SOJ-40_10.16mm_P1.27mm
IC25: 74HC139; SOIC-16_3.9x9.9mm_P1.27mm
L15, L16, L17: 2R2; L_Acorn_8x3mm
LK20: Ras_sel; PinHeader_1x03_P2.54mm_Vertical
LK21: Ra9_sel; PinHeader_1x02_P2.54mm_Vertical
LK22: S1_sel; PinHeader_1x03_P2.54mm_Vertical
R125: 100K; R_0805_2012Metric
R130: 4K7; R_0805_2012Metric
R132, R133, R134, R137: 68R; R_0805_2012Metric
R135: 330R; R_0805_2012Metric
R136: 10K; R_0805_2012Metric
RP2, RP4, RP5, RP6: 68R; SOIC-16W_5.3x10.2mm_P1.27mm

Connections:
+5V: C131.1, C152.1, C160.1, C162.2, C163.1, C166.1, C228.1, IC6.11 (Vcc), IC6.16 (Vcc), IC6.30 (Vcc), IC11.11 (Vcc), IC11.16 (Vcc), IC11.30 (Vcc), IC21.1 (Vcc), IC21.6 (Vcc), IC21.20 (Vcc), IC22.1 (Vcc), IC22.6 (Vcc), IC22.20 (Vcc), IC25.13 (A1), IC25.14 (A0), IC25.15 (E), IC25.16 (VCC), L15.1, L16.1, L17.1, R125.2, R130.1, R136.1; also elsewhere on the board
/CPU/Cas0: R137.2; also elsewhere on the board
/CPU/Cas1: R134.2; also elsewhere on the board
/CPU/Cas2: R133.1; also elsewhere on the board
/CPU/Cas3: R132.1; also elsewhere on the board
/CPU/D0: RP2.8 (R8.1); also elsewhere on the board
/CPU/D1: RP2.7 (R7.1); also elsewhere on the board
/CPU/D2: RP2.6 (R6.1); also elsewhere on the board
/CPU/D3: RP2.5 (R5.1); also elsewhere on the board
/CPU/D4: RP2.4 (R4.1); also elsewhere on the board
/CPU/D5: RP2.3 (R3.1); also elsewhere on the board
/CPU/D6: RP2.2 (R2.1); also elsewhere on the board
/CPU/D7: RP2.1 (R1.1); also elsewhere on the board
/CPU/D8: RP4.8 (R8.1); also elsewhere on the board
/CPU/D9: RP4.7 (R7.1); also elsewhere on the board
/CPU/D10: RP4.6 (R6.1); also elsewhere on the board
/CPU/D11: RP4.5 (R5.1); also elsewhere on the board
/CPU/D12: RP4.4 (R4.1); also elsewhere on the board
/CPU/D13: RP4.3 (R3.1); also elsewhere on the board
/CPU/D14: RP4.2 (R2.1); also elsewhere on the board
/CPU/D15: RP4.1 (R1.1); also elsewhere on the board
/CPU/D16: RP5.8 (R8.1); also elsewhere on the board
/CPU/D17: RP5.7 (R7.1); also elsewhere on the board
/CPU/D18: RP5.6 (R6.1); also elsewhere on the board
/CPU/D19: RP5.5 (R5.1); also elsewhere on the board
/CPU/D20: RP5.4 (R4.1); also elsewhere on the board
/CPU/D21: RP5.3 (R3.1); also elsewhere on the board
/CPU/D22: RP5.2 (R2.1); also elsewhere on the board
/CPU/D23: RP5.1 (R1.1); also elsewhere on the board
/CPU/D24: RP6.8 (R8.1); also elsewhere on the board
/CPU/D25: RP6.7 (R7.1); also elsewhere on the board
/CPU/D26: RP6.6 (R6.1); also elsewhere on the board
/CPU/D27: RP6.5 (R5.1); also elsewhere on the board
/CPU/D28: RP6.4 (R4.1); also elsewhere on the board
/CPU/D29: RP6.3 (R3.1); also elsewhere on the board
/CPU/D30: RP6.2 (R2.1); also elsewhere on the board
/CPU/D31: RP6.1 (R1.1); also elsewhere on the board
/CPU/Ra0: IC6.26 (A0), IC11.26 (A0), IC21.16 (A0), IC22.16 (A0); also elsewhere on the board
/CPU/Ra1: IC6.27 (A1), IC11.27 (A1), IC21.17 (A1), IC22.17 (A1); also elsewhere on the board
/CPU/Ra2: IC6.28 (A2), IC11.28 (A2), IC21.18 (A2), IC22.18 (A2); also elsewhere on the board
/CPU/Ra3: IC6.29 (A3), IC11.29 (A3), IC21.19 (A3), IC22.19 (A3); also elsewhere on the board
/CPU/Ra4: IC6.32 (A4), IC11.32 (A4), IC21.22 (A4), IC22.22 (A4); also elsewhere on the board
/CPU/Ra5: IC6.33 (A5), IC11.33 (A5), IC21.23 (A5), IC22.23 (A5); also elsewhere on the board
/CPU/Ra6: IC6.34 (A6), IC11.34 (A6), IC21.24 (A6), IC22.24 (A6); also elsewhere on the board
/CPU/Ra7: IC6.35 (A7), IC11.35 (A7), IC21.25 (A7), IC22.25 (A7); also elsewhere on the board
/CPU/Ra8: IC6.36 (A8), IC11.36 (A8), IC21.26 (A8), IC22.26 (A8); also elsewhere on the board
/CPU/Ra9: LK21.2, LK22.3; also elsewhere on the board
/RAM/Ra94m: IC6.22 (NC/A9), IC11.22 (NC/A9), LK21.1
/RAM/Rd0: IC6.12 (IO0), IC22.2 (IO0), RP2.9 (R8.2)
/RAM/Rd1: IC6.13 (IO1), IC22.3 (IO1), RP2.10 (R7.2)
/RAM/Rd2: IC6.14 (IO2), IC22.4 (IO2), RP2.11 (R6.2)
/RAM/Rd3: IC6.15 (IO3), IC22.5 (IO3), RP2.12 (R5.2)
/RAM/Rd4: IC6.17 (IO4), IC22.7 (IO4), RP2.13 (R4.2)
/RAM/Rd5: IC6.18 (IO5), IC22.8 (IO5), RP2.14 (R3.2)
/RAM/Rd6: IC6.19 (IO6), IC22.9 (IO6), RP2.15 (R2.2)
/RAM/Rd7: IC6.20 (IO7), IC22.10 (IO7), RP2.16 (R1.2)
/RAM/Rd8: IC6.1 (IO8), IC22.31 (IO8), RP4.9 (R8.2)
/RAM/Rd9: IC6.2 (IO9), IC22.32 (IO9), RP4.10 (R7.2)
/RAM/Rd10: IC6.3 (IO10), IC22.33 (IO10), RP4.11 (R6.2)
/RAM/Rd11: IC6.4 (IO11), IC22.34 (IO11), RP4.12 (R5.2)
/RAM/Rd12: IC6.6 (IO12), IC22.36 (IO12), RP4.13 (R4.2)
/RAM/Rd13: IC6.7 (IO13), IC22.37 (IO13), RP4.14 (R3.2)
/RAM/Rd14: IC6.8 (IO14), IC22.38 (IO14), RP4.15 (R2.2)
/RAM/Rd15: IC6.9 (IO15), IC22.39 (IO15), RP4.16 (R1.2)
/RAM/Rd16: IC11.12 (IO0), IC21.2 (IO0), RP5.9 (R8.2)
/RAM/Rd17: IC11.13 (IO1), IC21.3 (IO1), RP5.10 (R7.2)
/RAM/Rd18: IC11.14 (IO2), IC21.4 (IO2), RP5.11 (R6.2)
/RAM/Rd19: IC11.15 (IO3), IC21.5 (IO3), RP5.12 (R5.2)
/RAM/Rd20: IC11.17 (IO4), IC21.7 (IO4), RP5.13 (R4.2)
/RAM/Rd21: IC11.18 (IO5), IC21.8 (IO5), RP5.14 (R3.2)
/RAM/Rd22: IC11.19 (IO6), IC21.9 (IO6), RP5.15 (R2.2)
/RAM/Rd23: IC11.20 (IO7), IC21.10 (IO7), RP5.16 (R1.2)
/RAM/Rd24: IC11.1 (IO8), IC21.31 (IO8), RP6.9 (R8.2)
/RAM/Rd25: IC11.2 (IO9), IC21.32 (IO9), RP6.10 (R7.2)
/RAM/Rd26: IC11.3 (IO10), IC21.33 (IO10), RP6.11 (R6.2)
/RAM/Rd27: IC11.4 (IO11), IC21.34 (IO11), RP6.12 (R5.2)
/RAM/Rd28: IC11.6 (IO12), IC21.36 (IO12), RP6.13 (R4.2)
/RAM/Rd29: IC11.7 (IO13), IC21.37 (IO13), RP6.14 (R3.2)
/RAM/Rd30: IC11.8 (IO14), IC21.38 (IO14), RP6.15 (R2.2)
/RAM/Rd31: IC11.9 (IO15), IC21.39 (IO15), RP6.16 (R1.2)
/RAM/Tcas0: IC6.39 (~LCAS), IC22.29 (~LCAS), R137.1
/RAM/Tcas1: IC6.38 (~UCAS), IC22.28 (~UCAS), R134.1
/RAM/Tcas2: IC11.39 (~LCAS), IC21.29 (~LCAS), R133.2
/RAM/Tcas3: IC11.38 (~UCAS), IC21.28 (~UCAS), R132.2
/RAM/~OE1: IC21.27 (~OE), IC22.27 (~OE), IC25.4 (O0)
/RAM/~OE2: IC6.37 (~OE), IC11.37 (~OE), IC25.6 (O2)
/RAM/~WR1: IC21.13 (~WE), IC22.13 (~WE), IC25.5 (O1)
/RAM/~WR2: IC6.23 (~WE), IC11.23 (~WE), IC25.7 (O3)
Dbe: IC25.2 (A0); also elsewhere on the board
GND: C131.2, C152.2, C159.2, C160.2, C162.1, C163.2, C164.2, C165.2, C166.2, C228.2, IC6.5 (Vss), IC6.10 (Vss), IC6.31 (Vss), IC11.5 (Vss), IC11.10 (Vss), IC11.31 (Vss), IC21.21 (Vss), IC21.35 (Vss), IC21.40 (Vss), IC22.21 (Vss), IC22.35 (Vss), IC22.40 (Vss), IC25.8 (GND), LK22.1, R135.1; also elsewhere on the board
unnamed: C159.1, L15.2
unnamed: C164.1, L17.2
unnamed: C165.1, L16.2
unnamed: IC21.14 (~RAS), IC22.14 (~RAS), LK20.2, R125.1
unnamed: IC25.3 (A1), LK22.2, R136.2
unnamed: IC25.1 (E), R135.2
unnamed: LK20.3, R130.2
~Ras: IC6.24 (~RAS), IC11.24 (~RAS), LK20.1; also elsewhere on the board

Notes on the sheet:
DRAM Size Selection Size LK22 LK21 LK20 1M 1-2 NC 1-2 2M 2-3 NC 1-2 4M NC 1-2 2-3

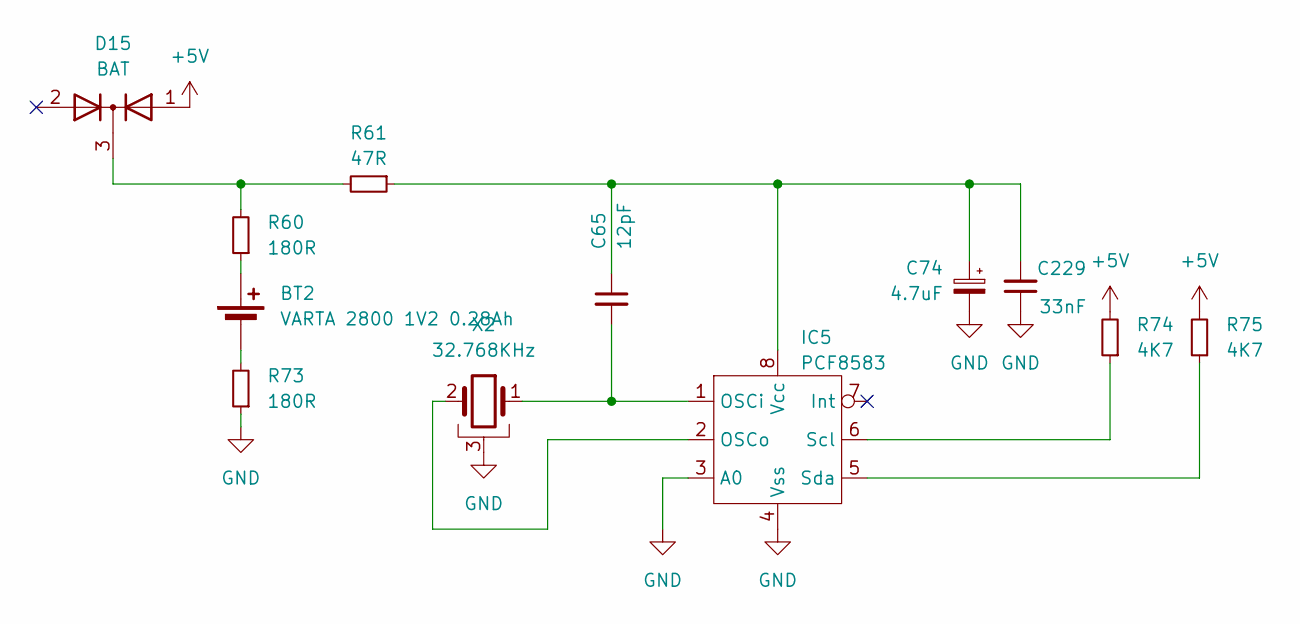
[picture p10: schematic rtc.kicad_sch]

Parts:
BT2: VARTA 2800 1V2 0.28Ah; Varta-2800
C65: 12pF; C_0805_2012Metric
C74: 4.7uF; CP_Radial_D8.0mm_P5.00mm
C229: 33nF; C_0805_2012Metric
D15: BAT; SOT-23-3
IC5: PCF8583; SOIC-8_7.5x5.85mm_P1.27mm
R60, R73: 180R; R_0805_2012Metric
R61: 47R; R_0805_2012Metric
R74, R75: 4K7; R_0805_2012Metric
X2: 32.768KHz; Crystal_AT310_D3.0mm_L10.0mm_Horizontal_1EP_style2

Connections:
+5V: D15.1 (A), R74.2, R75.2; also elsewhere on the board
GND: C74.2, C229.1, IC5.3 (A0), IC5.4 (Vss), R73.1, X2.3; also elsewhere on the board
unnamed: BT2.1 (+), R60.1
unnamed: BT2.2 (-), R73.2
unnamed: D15.3 (K), R60.2, R61.2
unnamed: C65.2, IC5.1 (OSCi), X2.1
unnamed: IC5.2 (OSCo), X2.2
unnamed: IC5.6 (Scl), R74.1
unnamed: IC5.5 (Sda), R75.1
unnamed: C65.1, C74.1, C229.2, IC5.8 (Vcc), R61.1

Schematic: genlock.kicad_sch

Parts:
IC8: 74HCT14; SOIC-14_3.9x8.7mm_P1.27mm
LK6: Conn_02x04_Odd_Even; PinHeader_2x04_P2.54mm_Vertical

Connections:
Clkvid: LK6.5; also elsewhere on the board
GND: LK6.3, LK6.8; also elsewhere on the board
HS: IC8.3; also elsewhere on the board
IV/CS: IC8.6, LK6.1; also elsewhere on the board
unnamed: IC8.4, LK6.2
Vidclk: LK6.6; also elsewhere on the board
V/CS: IC8.5; also elsewhere on the board
sink: LK6.4; also elsewhere on the board
~Sup: LK6.7; also elsewhere on the board

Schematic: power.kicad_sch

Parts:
C14, C16, C28, C161: 47uF; CP_Radial_D8.0mm_P5.00mm
C24, C29, C37, C38, C40, C50, C64, C66, C67, C70, C71, C85, C91, C92, C95, C103, C107, C109, C116, C117, C138, C151, C222, C223, C227: 33nF; C_0805_2012Metric
C39, C49, C59: 220uF; CP_Radial_Tantal_D8.0mm_P5.00mm
C83: 10uF; CP_Radial_Tantal_D8.0mm_P5.00mm
C106: 10uF; CP_Radial_Tantal_D9.0mm_P5.00mm
FS1: Fuse 0A25; Fuseholder_Clip-5x20mm_Bel_FC-203-22_Lateral_P17.80x5.00mm_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
L6, L13: 2R2; L_Acorn_8x3mm
LK13: RFI GND; PinHeader_1x02_P2.54mm_Vertical; not fitted
MW1: RPT-60B; RPT-60
PL1: Mains Input; AC_Power_Header
PL2: 0V; Molex_19708-4003
PL3: Earth; Molex_19708-4003
PL4: +5V; Molex_19708-4003
PL5: FDD Power; Molex_KK-254_AE-6410-04A_1x04_P2.54mm_Vertical
SW2: SW_DPST; Power_Switch
TP2: +12V; PinHeader_1x01_P2.54mm_Vertical
TP3: -12V; PinHeader_1x01_P2.54mm_Vertical

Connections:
+5C: C70.2, C106.1, C107.2, C109.2, L13.1; also elsewhere on the board
+5V: C24.2, C37.2, C38.2, C39.1, C40.2, C49.1, C50.2, C59.1, C64.2, C66.2, C67.2, C71.2, C83.1, C85.2, C91.2, C92.2, C95.2, C103.2, C138.2, C151.2, C161.1, C227.2, L6.1, L13.2, MW1.3 (+5V), MW1.4 (+5V), PL4.1; also elsewhere on the board
+12V: C14.1, C117.2, C222.2, MW1.7 (+12V), TP2.1; also elsewhere on the board
-12V: C16.2, C116.1, C223.1, MW1.8 (-12V), TP3.1; also elsewhere on the board
Earth: LK13.2
GND: C14.2, C16.1, C24.1, C28.2, C29.1, C37.1, C38.1, C39.2, C40.1, C49.2, C50.1, C59.2, C64.1, C66.1, C67.1, C70.1, C71.1, C83.2, C85.1, C91.1, C92.1, C95.1, C103.1, C106.2, C107.1, C109.1, C116.2, C117.1, C138.1, C151.1, C161.2, C222.1, C223.2, C227.1, MW1.5 (GND), MW1.6 (GND), PL2.1, PL3.1, PL5.2, PL5.3; also elsewhere on the board
unnamed: FS1.1, SW2.4
unnamed: FS1.2, MW1.1 (AC/L)
unnamed: MW1.2 (AC/N), SW2.2
unnamed: PL1.1, SW2.3
unnamed: PL1.2, SW2.1
unnamed: C28.1, C29.2, L6.2, PL5.1
SndVSS: LK13.1; also elsewhere on the board

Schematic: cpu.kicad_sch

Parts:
C84: 10uF; CP_Radial_D4.0mm_P2.00mm
C94, C100, C101, C102, C119: 33nF; C_0805_2012Metric
C98, C99, C224: 12pF; C_0805_2012Metric
C120: 10uF; CP_Radial_Tantal_D7.0mm_P5.00mm
CX1: 47pF; C_Axial_L5.1mm_D3.1mm_P12.50mm_Horizontal
D19: BAT; SOT-23-3
IC8: 74HCT14; SOIC-14_3.9x8.7mm_P1.27mm
IC12: DS2401+; TO-92_Inline_Wide
IC13: ARM250; PQFP-160_28x28mm_P0.65mm
IC20: 74HC138; SOIC-16_3.9x9.9mm_P1.27mm
IC27: 74AC32; SOIC-14_3.9x8.7mm_P1.27mm
R50, R110, R115, R124, R219: 68R; R_0805_2012Metric
R83, R84, R85, R86, R87, R88, R89, R91: 4K7; R_0805_2012Metric
R94: 100K; R_0805_2012Metric
R97: 22R; R_0805_2012Metric
R104: 1M0; R_0805_2012Metric
R218: 47R; R_0805_2012Metric
R223: 220R; R_0805_2012Metric
R228: 33R; R_0805_2012Metric
RP7: 68R; SOIC-16W_5.3x10.2mm_P1.27mm
RP11: 100K; SOIC-16W_5.3x10.2mm_P1.27mm
TP1: C1; TestPoint_Pad_D1.0mm
TP4: Test; TestPoint_Pad_D1.0mm
TP6: C0; TestPoint_Pad_D1.0mm
TP27: compSync; TestPoint_Pad_D1.0mm
TP33: ~{EFiq}; TestPoint_Pad_D1.0mm
TP34: C2; TestPoint_Pad_D1.0mm
X4: 72.0MHz; Oscillator_DIP-14
X5: 25.175MHz; Crystal_HC49-4H_Vertical

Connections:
+5V: C94.1, C100.1, C101.1, C102.1, C119.1, C120.1, D19.3 (K), IC8.14 (VCC), IC13.10 (Vdd), IC13.29 (Vdd), IC13.50 (Vdd), IC13.68 (Vdd), IC13.90 (Vdd), IC13.108 (Vdd), IC13.127 (Vdd), IC13.147 (Vdd), IC20.6 (E3), IC20.16 (VCC), IC27.14 (VCC), R83.2, R84.2, R85.2, R86.2, R87.2, R88.2, R89.1, R91.1, R94.1, RP11.1 (R1.1), RP11.2 (R2.1), RP11.3 (R3.1), RP11.4 (R4.1), RP11.5 (R5.1), RP11.6 (R6.1), RP11.7 (R7.1), RP11.8 (R8.1), X4.1 (EN), X4.14 (Vcc); also elsewhere on the board
/CPU/Bd0: IC13.148 (Bd0), RP11.16 (R1.2); also elsewhere on the board
/CPU/Bd1: IC13.149 (Bd1), RP11.15 (R2.2); also elsewhere on the board
/CPU/Bd2: IC13.150 (Bd2), RP11.14 (R3.2); also elsewhere on the board
/CPU/Bd3: IC13.151 (Bd3), RP11.13 (R4.2); also elsewhere on the board
/CPU/Bd4: IC13.152 (Bd4), RP11.12 (R5.2); also elsewhere on the board
/CPU/Bd5: IC13.153 (Bd5), RP11.11 (R6.2); also elsewhere on the board
/CPU/Bd6: IC13.154 (Bd6), RP11.10 (R7.2); also elsewhere on the board
/CPU/Bd7: IC13.155 (Bd7), RP11.9 (R8.2); also elsewhere on the board
/CPU/Cas0: IC13.24 (~Cas0); also elsewhere on the board
/CPU/Cas1: IC13.25 (~Cas1); also elsewhere on the board
/CPU/Cas2: IC13.26 (~Cas2); also elsewhere on the board
/CPU/Cas3: IC13.27 (~Cas3); also elsewhere on the board
/CPU/D0: IC13.41 (D0); also elsewhere on the board
/CPU/D1: IC13.42 (D1); also elsewhere on the board
/CPU/D2: IC13.43 (D2); also elsewhere on the board
/CPU/D3: IC13.44 (D3); also elsewhere on the board
/CPU/D4: IC13.45 (D4); also elsewhere on the board
/CPU/D5: IC13.46 (D5); also elsewhere on the board
/CPU/D6: IC13.47 (D6); also elsewhere on the board
/CPU/D7: IC13.48 (D7); also elsewhere on the board
/CPU/D8: IC13.51 (D8); also elsewhere on the board
/CPU/D9: IC13.52 (D9); also elsewhere on the board
/CPU/D10: IC13.53 (D10); also elsewhere on the board
/CPU/D11: IC13.54 (D11); also elsewhere on the board
/CPU/D12: IC13.55 (D12); also elsewhere on the board
/CPU/D13: IC13.56 (D13); also elsewhere on the board
/CPU/D14: IC13.57 (D14); also elsewhere on the board
/CPU/D15: IC13.58 (D15); also elsewhere on the board
/CPU/D16: IC13.59 (D16); also elsewhere on the board
/CPU/D17: IC13.60 (D17); also elsewhere on the board
/CPU/D18: IC13.61 (D18); also elsewhere on the board
/CPU/D19: IC13.62 (D19); also elsewhere on the board
/CPU/D20: IC13.63 (D20); also elsewhere on the board
/CPU/D21: IC13.64 (D21); also elsewhere on the board
/CPU/D22: IC13.65 (D22); also elsewhere on the board
/CPU/D23: IC13.66 (D23); also elsewhere on the board
/CPU/D24: IC13.69 (D24); also elsewhere on the board
/CPU/D25: IC13.70 (D25); also elsewhere on the board
/CPU/D26: IC13.71 (D26); also elsewhere on the board
/CPU/D27: IC13.72 (D27); also elsewhere on the board
/CPU/D28: IC13.73 (D28); also elsewhere on the board
/CPU/D29: IC13.74 (D29); also elsewhere on the board
/CPU/D30: IC13.75 (D30); also elsewhere on the board
/CPU/D31: IC13.76 (D31); also elsewhere on the board
/CPU/La2: IC13.79 (La2); also elsewhere on the board
/CPU/La3: IC13.80 (La3); also elsewhere on the board
/CPU/La4: IC13.81 (La4); also elsewhere on the board
/CPU/La5: IC13.82 (La5); also elsewhere on the board
/CPU/La6: IC13.83 (La6); also elsewhere on the board
/CPU/La7: IC13.84 (La7); also elsewhere on the board
/CPU/La8: IC13.85 (La8); also elsewhere on the board
/CPU/La9: IC13.86 (La9); also elsewhere on the board
/CPU/La10: IC13.87 (La10); also elsewhere on the board
/CPU/La11: IC13.88 (La11); also elsewhere on the board
/CPU/La12: IC13.91 (La12); also elsewhere on the board
/CPU/La13: IC13.92 (La13); also elsewhere on the board
/CPU/La14: IC13.93 (La14), IC20.1 (A0); also elsewhere on the board
/CPU/La15: IC13.94 (La15), IC20.2 (A1); also elsewhere on the board
/CPU/La16: IC13.95 (La16), IC20.3 (A2); also elsewhere on the board
/CPU/La17: IC13.96 (La17), IC20.4 (E1); also elsewhere on the board
/CPU/La18: IC13.97 (La18); also elsewhere on the board
/CPU/La19: IC13.98 (La19); also elsewhere on the board
/CPU/La20: IC13.99 (La20); also elsewhere on the board
/CPU/La21: IC13.100 (La21), IC20.5 (E2); also elsewhere on the board
/CPU/Ra0: RP7.9 (R8.2); also elsewhere on the board
/CPU/Ra1: RP7.10 (R7.2); also elsewhere on the board
/CPU/Ra2: RP7.11 (R6.2); also elsewhere on the board
/CPU/Ra3: RP7.12 (R5.2); also elsewhere on the board
/CPU/Ra4: RP7.13 (R4.2); also elsewhere on the board
/CPU/Ra5: RP7.14 (R3.2); also elsewhere on the board
/CPU/Ra6: RP7.15 (R2.2); also elsewhere on the board
/CPU/Ra7: RP7.16 (R1.2); also elsewhere on the board
/CPU/Ra8: R124.2; also elsewhere on the board
/CPU/Ra9: R115.2; also elsewhere on the board
Aen: IC13.102 (Aen); also elsewhere on the board
B: IC13.120 (Bout); also elsewhere on the board
C0: IC13.136 (C0), TP6.1; also elsewhere on the board
C1: IC13.137 (C1), TP1.1; also elsewhere on the board
CLK2: R218.2; also elsewhere on the board
Clkvid: IC13.124 (Clkvid); also elsewhere on the board
Dbe: IC13.40 (Dbe); also elsewhere on the board
Drq: IC13.129 (Drq); also elsewhere on the board
G: IC13.119 (Gout); also elsewhere on the board
GND: C84.2, C94.2, C100.2, C101.2, C102.2, C119.2, C120.2, C224.2, IC8.7 (GND), IC12.1 (GND), IC13.9 (Vss), IC13.18 (Vss), IC13.28 (Vss), IC13.49 (Vss), IC13.67 (Vss), IC13.89 (Vss), IC13.107 (Vss), IC13.126 (Vss), IC13.146 (Vss), IC20.8 (GND), IC27.4, IC27.5, IC27.7 (GND), IC27.9, IC27.10, IC27.12, IC27.13, X4.7 (GND); also elsewhere on the board
HS: IC13.19 (Eorh); also elsewhere on the board
ID0: IC13.13 (Mid0); also elsewhere on the board
ID1: IC13.14 (Mid1); also elsewhere on the board
ID2: IC13.15 (Mid2); also elsewhere on the board
ID3: IC13.16 (Mid3); also elsewhere on the board
Kin: IC13.2 (Kin); also elsewhere on the board
Kout: IC13.3 (Kout); also elsewhere on the board
Left+: IC13.112 (Lch); also elsewhere on the board
Left-: IC13.113 (Lch-); also elsewhere on the board
unnamed: C98.2, C99.2, CX1.1
unnamed: C99.1, X5.1
unnamed: C224.1, IC27.1, R223.1
unnamed: IC12.2 (DQ), IC13.139 (C3), R89.2
unnamed: IC13.138 (C2), R88.1, TP34.1
unnamed: IC13.135 (Clk2), R218.1
unnamed: IC13.12 (Clk25in), R104.1
unnamed: C98.1, IC13.11 (Clk25out), R104.2, X5.2
unnamed: IC13.4 (Clk72), R97.1
unnamed: IC13.17 (Clkkb), R50.1
unnamed: IC13.30 (Ra0), RP7.8 (R8.1)
unnamed: IC13.31 (Ra1), RP7.7 (R7.1)
unnamed: IC13.32 (Ra2), RP7.6 (R6.1)
unnamed: IC13.33 (Ra3), RP7.5 (R5.1)
unnamed: IC13.34 (Ra4), RP7.4 (R4.1)
unnamed: IC13.35 (Ra5), RP7.3 (R3.1)
unnamed: IC13.36 (Ra6), RP7.2 (R2.1)
unnamed: IC13.37 (Ra7), RP7.1 (R1.1)
unnamed: IC13.38 (Ra8), R124.1
unnamed: IC13.39 (Ra9), R115.1
unnamed: IC13.143 (~I13), R91.2
unnamed: IC13.141 (~Iogt), R228.2
unnamed: IC13.140 (~Iorq), IC27.2, R223.2
unnamed: C84.1, D19.1 (A), IC13.7 (~Por), R94.2
unnamed: IC13.5 (~Test), TP4.1
unnamed: IC27.3, R219.2
unnamed: R97.2, X4.8 (OUT)
Pr/Nw: IC13.78 (Pr/nw); also elsewhere on the board
R: IC13.118 (Rout); also elsewhere on the board
Ref8M: IC13.145 (Ioclk); also elsewhere on the board
Right+: IC13.114 (Rch); also elsewhere on the board
Right-: IC13.115 (Rch-); also elsewhere on the board
Rst: IC8.8; also elsewhere on the board
SndRef: IC13.109 (Rsdac); also elsewhere on the board
SndVDD: IC13.111 (Sndvdd); also elsewhere on the board
SndVSS: IC13.110 (Sndvss); also elsewhere on the board
Tc: IC13.106 (Tc); also elsewhere on the board
VidRef: IC13.116 (Rvdac); also elsewhere on the board
Vidclk: IC13.123 (Vidclk); also elsewhere on the board
Vidvss: IC13.117 (Vidvss); also elsewhere on the board
V/CS: IC13.20 (Eorv); also elsewhere on the board
clkkb: R50.2; also elsewhere on the board
compsync: IC13.125 (Csync), TP27.1
sink: IC13.121 (Sink); also elsewhere on the board
~Bl: IC13.159 (~Rbl); also elsewhere on the board
~Dack: IC13.105 (~Dack); also elsewhere on the board
~EFiq: IC13.134 (Efiq), R87.1, TP33.1
~Fintr: IC13.132 (~Fintr), R85.1; also elsewhere on the board
~Index: IC13.128 (~Index); also elsewhere on the board
~Iogt: R228.1; also elsewhere on the board
~Iorq: R219.1; also elsewhere on the board
~Ior: IC13.103 (~Ior); also elsewhere on the board
~Iow: IC13.104 (~Iow); also elsewhere on the board
~Joyst1: IC13.21 (~Joy1); also elsewhere on the board
~Joyst2: IC13.22 (~Joy2); also elsewhere on the board
~Mcras: IC13.23 (~Ras), R110.1
~Ms1: IC20.14 (O1); also elsewhere on the board
~Pfiq: IC13.131 (~Pfiq), R84.1; also elsewhere on the board
~Pint: IC13.101 (~Pintr); also elsewhere on the board
~Pirq: IC13.130 (~Pirq), R83.1; also elsewhere on the board
~Pre: IC13.1 (~Re); also elsewhere on the board
~Ps1: IC13.142 (~Ps1); also elsewhere on the board
~Pwe: IC13.160 (~We); also elsewhere on the board
~Ras: R110.2; also elsewhere on the board
~Romcs: IC13.77 (~Romcs); also elsewhere on the board
~Rst: CX1.2, IC8.9, IC13.6 (~Rst); also elsewhere on the board
~Sintr: IC13.133 (~Sintr), R86.1; also elsewhere on the board
~Sup: IC13.122 (~Sup); also elsewhere on the board

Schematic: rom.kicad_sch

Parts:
C121, C130: 33nF; C_0805_2012Metric
C140: 100nF; C_0805_2012Metric
IC17: 0296061; DIP-42_W15.24mm
IC18: 0296062; DIP-42_W15.24mm
LK16: Conn_01x06; PinHeader_1x06_P2.54mm_Vertical
R113: 22R; R_0805_2012Metric
R114: 330R; R_0805_2012Metric

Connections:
+5V: C121.1, C130.1, C140.2, IC17.22 (Vcc), IC17.32 (BHE), IC18.22 (Vcc), IC18.32 (BHE), LK16.1; also elsewhere on the board
/CPU/D0: IC17.14 (D0), LK16.2; also elsewhere on the board
/CPU/D1: IC17.16 (D1); also elsewhere on the board
/CPU/D2: IC17.18 (D2); also elsewhere on the board
/CPU/D3: IC17.20 (D3); also elsewhere on the board
/CPU/D4: IC17.23 (D4); also elsewhere on the board
/CPU/D5: IC17.25 (D5); also elsewhere on the board
/CPU/D6: IC17.27 (D6); also elsewhere on the board
/CPU/D7: IC17.29 (D7); also elsewhere on the board
/CPU/D8: IC17.15 (D8); also elsewhere on the board
/CPU/D9: IC17.17 (D9); also elsewhere on the board
/CPU/D10: IC17.19 (D10); also elsewhere on the board
/CPU/D11: IC17.21 (D11); also elsewhere on the board
/CPU/D12: IC17.24 (D12); also elsewhere on the board
/CPU/D13: IC17.26 (D13); also elsewhere on the board
/CPU/D14: IC17.28 (D14); also elsewhere on the board
/CPU/D15: IC17.30 (D15); also elsewhere on the board
/CPU/D16: IC18.14 (D0); also elsewhere on the board
/CPU/D17: IC18.16 (D1); also elsewhere on the board
/CPU/D18: IC18.18 (D2); also elsewhere on the board
/CPU/D19: IC18.20 (D3); also elsewhere on the board
/CPU/D20: IC18.23 (D4); also elsewhere on the board
/CPU/D21: IC18.25 (D5); also elsewhere on the board
/CPU/D22: IC18.27 (D6); also elsewhere on the board
/CPU/D23: IC18.29 (D7); also elsewhere on the board
/CPU/D24: IC18.15 (D8); also elsewhere on the board
/CPU/D25: IC18.17 (D9); also elsewhere on the board
/CPU/D26: IC18.19 (D10); also elsewhere on the board
/CPU/D27: IC18.21 (D11); also elsewhere on the board
/CPU/D28: IC18.24 (D12); also elsewhere on the board
/CPU/D29: IC18.26 (D13); also elsewhere on the board
/CPU/D30: IC18.28 (D14); also elsewhere on the board
/CPU/D31: IC18.30 (D15); also elsewhere on the board
/CPU/La2: IC17.10 (A0), IC18.10 (A0); also elsewhere on the board
/CPU/La3: IC17.9 (A1), IC18.9 (A1); also elsewhere on the board
/CPU/La4: IC17.8 (A2), IC18.8 (A2); also elsewhere on the board
/CPU/La5: IC17.7 (A3), IC18.7 (A3); also elsewhere on the board
/CPU/La6: IC17.6 (A4), IC18.6 (A4); also elsewhere on the board
/CPU/La7: IC17.5 (A5), IC18.5 (A5); also elsewhere on the board
/CPU/La8: IC17.4 (A6), IC18.4 (A6); also elsewhere on the board
/CPU/La9: IC17.3 (A7), IC18.3 (A7); also elsewhere on the board
/CPU/La10: IC17.41 (A8), IC18.41 (A8); also elsewhere on the board
/CPU/La11: IC17.40 (A9), IC18.40 (A9); also elsewhere on the board
/CPU/La12: IC17.39 (A10), IC18.39 (A10); also elsewhere on the board
/CPU/La13: IC17.38 (A11), IC18.38 (A11); also elsewhere on the board
/CPU/La14: IC17.37 (A12), IC18.37 (A12); also elsewhere on the board
/CPU/La15: IC17.36 (A13), IC18.36 (A13); also elsewhere on the board
/CPU/La16: IC17.35 (A14), IC18.35 (A14); also elsewhere on the board
/CPU/La17: IC17.34 (A15), IC18.34 (A15); also elsewhere on the board
/CPU/La18: IC17.33 (A16), IC18.33 (A16); also elsewhere on the board
/CPU/La19: IC17.2 (A17), IC18.2 (A17); also elsewhere on the board
/CPU/La20: IC17.1 (A18), IC18.1 (A18); also elsewhere on the board
/CPU/La21: IC17.42 (NC/A21), IC18.42 (NC/A21), LK16.3; also elsewhere on the board
GND: C121.2, C130.2, C140.1, IC17.12 (Vss), IC17.31 (Vss), IC18.12 (Vss), IC18.31 (Vss), LK16.6, R114.1; also elsewhere on the board
unnamed: IC17.11 (~CE), IC18.11 (~CE), R113.2
testak: IC17.13 (~OE), IC18.13 (~OE), LK16.4, R114.2
~Romcs: R113.1; also elsewhere on the board
~Rst: LK16.5; also elsewhere on the board

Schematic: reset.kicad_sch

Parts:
C1: 10uF; CP_Radial_D5.0mm_P2.50mm
IC8: 74HCT14; SOIC-14_3.9x8.7mm_P1.27mm
Q3: BC849; SOT-23
R1: 22K; R_0805_2012Metric
R2: 100R; R_0805_2012Metric
R16, R17: 2K2; R_0805_2012Metric
R18: 1K2; R_0805_2012Metric
SW1: SW_Push_DPDT; Reset_Switch
TP7: RESET; TestPoint_Pad_D1.0mm

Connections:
+5V: R1.1, R18.1; also elsewhere on the board
GND: C1.2, Q3.2 (E), R17.2, SW1.3 (C); also elsewhere on the board
unnamed: C1.1, IC8.11, R1.2, R2.2, TP7.1
unnamed: IC8.10, R16.1
unnamed: Q3.1 (B), R16.2, R17.1
~Reset: R2.1, SW1.2 (B); also elsewhere on the board
~Rst: Q3.3 (C), R18.2; also elsewhere on the board

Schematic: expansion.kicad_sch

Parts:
R90, R92: 1K2; R_0805_2012Metric
R217, R221, R227: 33R; R_0805_2012Metric
R220: 47R; R_0805_2012Metric
R222: 68R; R_0805_2012Metric
SK5, SK9: Conn_01x17_Socket; PinSocket_1x17_P2.54mm_Vertical
SK7, SK8: Conn_01x05_Socket; PinSocket_1x05_P2.54mm_Vertical

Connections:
+5V: R90.1, R92.2, SK5.1, SK5.17, SK8.5, SK9.2; also elsewhere on the board
/CPU/Bd0: SK5.7; also elsewhere on the board
/CPU/Bd1: SK5.8; also elsewhere on the board
/CPU/Bd2: SK5.9; also elsewhere on the board
/CPU/Bd3: SK5.10; also elsewhere on the board
/CPU/Bd4: SK5.11; also elsewhere on the board
/CPU/Bd5: SK5.12; also elsewhere on the board
/CPU/Bd6: SK5.13; also elsewhere on the board
/CPU/Bd7: SK5.14; also elsewhere on the board
/CPU/La2: SK5.5; also elsewhere on the board
/CPU/La3: SK5.6; also elsewhere on the board
/CPU/La4: SK9.5; also elsewhere on the board
/CPU/La5: SK9.6; also elsewhere on the board
/CPU/La6: SK9.7; also elsewhere on the board
/CPU/La7: SK9.8; also elsewhere on the board
/CPU/La8: SK9.10; also elsewhere on the board
/CPU/La9: SK9.11; also elsewhere on the board
/CPU/La10: SK9.12; also elsewhere on the board
/CPU/La11: SK9.13; also elsewhere on the board
/CPU/La12: SK9.14; also elsewhere on the board
/CPU/La13: SK9.15; also elsewhere on the board
C0: SK7.1; also elsewhere on the board
C1: SK7.2; also elsewhere on the board
CLK2: SK5.4; also elsewhere on the board
GND: SK5.16, SK8.1, SK9.1, SK9.9, SK9.17; also elsewhere on the board
unnamed: R221.2, SK5.2
unnamed: R220.2, SK5.3
unnamed: R92.1, R227.2, SK7.3
unnamed: R222.2, SK8.2
unnamed: R217.2, SK9.3
Pr/Nw: SK9.4; also elsewhere on the board
Ref8M: R222.1; also elsewhere on the board
~Bl: R227.1; also elsewhere on the board
~Iogt: R90.2, SK7.5; also elsewhere on the board
~Iorq: SK7.4; also elsewhere on the board
~Ms1: SK8.4; also elsewhere on the board
~Pfiq: SK8.3; also elsewhere on the board
~Pirq: SK9.16; also elsewhere on the board
~Pre: R217.1; also elsewhere on the board
~Ps1: R220.1; also elsewhere on the board
~Pwe: R221.1; also elsewhere on the board
~Rst: SK5.15; also elsewhere on the board

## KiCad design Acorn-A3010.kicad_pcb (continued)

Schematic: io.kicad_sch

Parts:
C15, C148: 4.7nF; C_Rect_L7.0mm_W2.5mm_P5.00mm
C108, C111, C112, C113, C114, C115, C122, C123, C125, C126, C132, C134, C136, C153, C154, C155, C156: 100pF; C_0805_2012Metric
C127, C133, C135, C141, C142, C143, C144, C145: 1nF; C_0805_2012Metric
C128, C129: 22pF; C_0805_2012Metric
C137, C146: 33nF; C_0805_2012Metric
C139: 10uF; CP_Radial_Tantal_D9.0mm_P5.00mm
C147, C158: 100nF; C_0805_2012Metric
C149: 2.7nF; C_0805_2012Metric
C150: 150nF 5%; C_Rect_L7.0mm_W2.5mm_P5.00mm
C157: 47uF; CP_Radial_D8.0mm_P5.00mm
CX2: 68pF; C_Disc_D4.3mm_W1.9mm_P5.00mm
D21: BAT; SOT-23-3
IC16, IC23: MC1489; SOIC-14_3.9x8.7mm_P1.27mm
IC19: MC1488; SOIC-14_3.9x8.7mm_P1.27mm
IC24: 82C711; PQFP-100_14x20mm_P0.65mm
L14: 2R2; L_Acorn_8x3mm
LK11: NF; PinHeader_1x02_P2.54mm_Vertical
LK18: Pren; PinHeader_1x02_P2.54mm_Vertical
PL8: Serial; DSUB-9_Male_Horizontal_P2.77x2.84mm_EdgePinOffset9.90mm_Hou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
PL9: 34WAYBOXPLUG; IDC-Header_2x17_P2.54mm_Vertical
R116, R117, R118, R121, R122, R123, R126, R131: 4K7; R_0805_2012Metric
R119: 10K; R_0805_2012Metric
R120: 33R; R_0805_2012Metric
R127: 6K81 1%; R_1206_3216Metric
R128: 18K2 1%; R_1206_3216Metric
R129: 1K2; R_0805_2012Metric
R138, R140, R141: 4K7; R_0805_2012Metric; not fitted
R139, R142, R143, R144, R145: 1K; R_0805_2012Metric
R215: 0R; R_0805_2012Metric
RP8, RP9: 33R; SOIC-16W_5.3x10.2mm_P1.27mm
RX1: 4k7; R_Axial_DIN0204_L3.6mm_D1.6mm_P5.08mm_Horizontal
SK10: Printer; DSUB-25_Female_Horizontal_P2.77x2.84mm_EdgePinOffset9.90mm_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
TP5: Filter; TestPoint_Pad_D1.0mm
TP8: PwrGd; TestPoint_Pad_D1.0mm
TP9: SetCur; TestPoint_Pad_D1.0mm
TP10: RVI; TestPoint_Pad_D1.0mm
TP11: AVcc; TestPoint_Pad_D1.0mm
X7: 24MHz; Crystal_HC50_Horizontal_1EP_style2

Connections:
+5C: C146.1, C157.1, IC16.14 (VCC), IC19.14 (VCC), IC23.14 (VCC), R116.2, R117.2, R118.2, R121.2, R126.2, R131.2; also elsewhere on the board
+5V: C137.1, C139.1, C158.1, IC24.15, IC24.72, L14.2, R119.1, R122.2, R123.2, R138.2, R139.2, R140.2, R141.2, R142.2, R143.2, R144.2, R145.2; also elsewhere on the board
-12V: IC19.1 (VEE); also elsewhere on the board
/CPU/Bd0: IC24.48 (D0); also elsewhere on the board
/CPU/Bd1: IC24.49 (D1); also elsewhere on the board
/CPU/Bd2: IC24.50 (D2); also elsewhere on the board
/CPU/Bd3: IC24.51 (D3); also elsewhere on the board
/CPU/Bd4: IC24.53 (D4); also elsewhere on the board
/CPU/Bd5: IC24.54 (D5); also elsewhere on the board
/CPU/Bd6: IC24.55 (D6); also elsewhere on the board
/CPU/Bd7: IC24.56 (D7); also elsewhere on the board
/CPU/La2: IC24.28 (A0); also elsewhere on the board
/CPU/La3: IC24.29 (A1); also elsewhere on the board
/CPU/La4: IC24.30 (A2); also elsewhere on the board
/CPU/La5: IC24.31 (A3); also elsewhere on the board
/CPU/La6: IC24.32 (A4); also elsewhere on the board
/CPU/La7: IC24.33 (A5); also elsewhere on the board
/CPU/La8: IC24.34 (A6); also elsewhere on the board
/CPU/La9: IC24.41 (A7); also elsewhere on the board
/CPU/La10: IC24.42 (A8); also elsewhere on the board
/CPU/La11: IC24.43 (A9); also elsewhere on the board
/IO/DC: IC24.17 (Dskchg), PL9.34, R145.1
/IO/Density: IC24.1 (Rpm/Lc), PL9.2, R138.1
/IO/~Dirin: IC24.7 (Dir), PL9.18
/IO/~MotorOn: IC24.2 (Mtr0), PL9.16, R141.1
/IO/~Readdata: IC24.16 (Rddata), PL9.30, R144.1
/IO/~Side1: IC24.11 (Hdsel), PL9.32
/IO/~Step: IC24.8 (Step), PL9.20
/IO/~Track00: IC24.13 (Trk0), PL9.26, R142.1
/IO/~Writedata: IC24.9 (Wrdata), PL9.22
/IO/~Writegate: IC24.10 (Wgate), PL9.24
/IO/~Writeprot: IC24.14 (Wrprt), PL9.28, R143.1
Aen: IC24.46 (Aen); also elsewhere on the board
Drq: IC24.52 (Fdrq); also elsewhere on the board
GND: C108.2, C111.2, C112.2, C113.2, C114.2, C115.2, C122.2, C123.2, C125.2, C126.2, C127.2, C128.2, C129.2, C132.2, C133.2, C134.2, C135.2, C136.2, C137.2, C139.2, C141.2, C142.2, C143.2, C144.2, C145.2, C146.2, C147.2, C153.2, C154.2, C155.2, C156.2, C157.2, C158.2, CX2.2, D21.1 (A), IC16.4 (InputB), IC16.7 (GND), IC19.2 (InputA), IC19.7 (GND), IC23.7 (GND), IC23.10 (InputC), IC23.13 (InputD), IC24.6, IC24.47, IC24.67, LK11.2, LK18.1, PL8.0 (PAD), PL8.5, PL9.3, PL9.5, PL9.7, PL9.9, PL9.11, PL9.13, PL9.15, PL9.17, PL9.19, PL9.21, PL9.23, PL9.25, PL9.27, PL9.29, PL9.31, PL9.33, SK10.0, SK10.18, SK10.19, SK10.20, SK10.21, SK10.22, SK10.23, SK10.24, SK10.25, X7.3; also elsewhere on the board
unnamed: C128.1, R215.2, X7.2
unnamed: C136.1, R120.2, R121.1, SK10.17
unnamed: C15.2, C148.1, C150.2, R129.1
unnamed: C122.1, IC16.1 (InputA), PL8.6
unnamed: IC16.3 (OutputA), IC24.80 (Dsr1)
unnamed: C108.1, IC16.10 (InputC), PL8.9
unnamed: IC16.8 (OutputC), IC24.84 (Ri1)
unnamed: C112.1, IC16.13 (InputD), PL8.8
unnamed: IC16.11 (OutputD), IC24.82 (Cts1)
unnamed: IC19.5 (InputB2), IC24.79 (Txd1)
unnamed: C113.1, IC19.6 (OutputB), PL8.3
unnamed: IC19.9 (InputC2), IC24.83 (Dtr1)
unnamed: C111.1, IC19.8 (OutputC), PL8.4
unnamed: IC19.12 (InputD2), IC24.81 (Rts1)
unnamed: C114.1, IC19.11 (OutputD), PL8.7
unnamed: C123.1, IC23.1 (InputA), PL8.1
unnamed: IC23.3 (OutputA), IC24.85 (Dcd1)
unnamed: C115.1, IC23.4 (InputB), PL8.2
unnamed: IC23.6 (OutputB), IC24.78 (Rxd1)
unnamed: IC24.62 (Ack), RP8.13 (R4.2)
unnamed: IC24.76 (Autofd), RP9.10 (R7.2)
unnamed: C147.1, IC24.100 (Avcc), L14.1, TP11.1
unnamed: C148.2, C149.2, IC24.98 (Avss), LK11.1, R127.2, R128.2
unnamed: IC24.61 (Busy), RP8.14 (R3.2)
unnamed: IC24.19 (Drvtyp), R122.1
unnamed: IC24.75 (Error), RP9.13 (R4.2)
unnamed: C150.1, IC24.95 (Fgnd250)
unnamed: C15.1, IC24.94 (Fgnd500)
unnamed: C149.1, IC24.96 (Filter), R129.2, TP5.1
unnamed: IC24.74 (Init), RP9.9 (R8.2)
unnamed: IC24.21 (Osc2), R215.1
unnamed: C129.1, IC24.20 (Oscl/Clk), X7.1
unnamed: IC24.71 (Pd0), RP9.12 (R5.2)
unnamed: IC24.70 (Pd1), RP9.14 (R3.2)
unnamed: IC24.69 (Pd2), RP9.15 (R2.2)
unnamed: IC24.68 (Pd3), RP9.16 (R1.2)
unnamed: IC24.66 (Pd4), RP8.9 (R8.2)
unnamed: IC24.65 (Pd5), RP8.10 (R7.2)
unnamed: IC24.64 (Pd6), RP8.11 (R6.2)
unnamed: IC24.63 (Pd7), RP8.12 (R5.2)
unnamed: IC24.60 (Pe), RP8.15 (R2.2)
unnamed: IC24.18 (Pren), LK18.2, R123.1
unnamed: IC24.58 (Pwrgd), R119.2, TP8.1
unnamed: IC24.97 (Rvi), R128.1, TP10.1
unnamed: IC24.99 (Setcur), R127.1, TP9.1
unnamed: IC24.73 (Sictin), R120.1
unnamed: IC24.59 (Slct), RP8.16 (R1.2)
unnamed: IC24.77 (Strobe), RP9.11 (R6.2)
unnamed: C156.1, RP8.1 (R1.1), SK10.13
unnamed: C155.1, RP8.2 (R2.1), SK10.12
unnamed: C154.1, R131.1, RP8.3 (R3.1), SK10.11
unnamed: C153.1, R126.1, RP8.4 (R4.1), SK10.10
unnamed: C145.1, RP8.5 (R5.1), SK10.9
unnamed: C144.1, RP8.6 (R6.1), SK10.8
unnamed: C143.1, RP8.7 (R7.1), SK10.7
unnamed: C142.1, RP8.8 (R8.1), SK10.6
unnamed: C141.1, RP9.1 (R1.1), SK10.5
unnamed: C135.1, RP9.2 (R2.1), SK10.4
unnamed: C133.1, RP9.3 (R3.1), SK10.3
unnamed: C132.1, RP9.4 (R4.1), SK10.15
unnamed: C127.1, RP9.5 (R5.1), SK10.2
unnamed: C125.1, R116.1, RP9.6 (R6.1), SK10.1
unnamed: C126.1, R117.1, RP9.7 (R7.1), SK10.14
unnamed: C134.1, R118.1, RP9.8 (R8.1), SK10.16
Rst: IC24.57 (Rst); also elsewhere on the board
Tc: IC24.35 (Tc); also elsewhere on the board
~Dack: IC24.36 (Dack); also elsewhere on the board
~Fintr: IC24.40 (Fintr); also elsewhere on the board
~Index: CX2.1, D21.3 (K), IC24.12 (Index), PL9.8, R139.1, RX1.1, RX1.2; also elsewhere on the board
~Ior: IC24.44 (Ior); also elsewhere on the board
~Iow: IC24.45 (Iow); also elsewhere on the board
~Pint: IC24.39 (Pintr); also elsewhere on the board
~Sel0: IC24.4 (Drv0), PL9.10, R140.1; also elsewhere on the board
~Sintr: IC24.38 (Irq4); also elsewhere on the board

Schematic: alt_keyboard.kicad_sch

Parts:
C3: 47nF; C_0805_2012Metric
IC8: 74HCT14; SOIC-14_3.9x8.7mm_P1.27mm
LK3: Conn_01x06; PinHeader_1x06_P2.54mm_Vertical
LK14: Conn_01x03; PinHeader_1x03_P2.54mm_Vertical
R62: 10K; R_0805_2012Metric
R63: 220R; R_0805_2012Metric
R213: 2K2; R_0805_2012Metric

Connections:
+5V: C3.1, LK3.4; also elsewhere on the board
GND: C3.2, LK3.3, R62.1; also elsewhere on the board
Kbkin: LK14.1; also elsewhere on the board
Kin: LK14.2; also elsewhere on the board
Kout: IC8.13; also elsewhere on the board
unnamed: IC8.1, R62.2, R213.1
unnamed: IC8.12, R63.1
unnamed: LK3.5, R213.2
unnamed: LK3.6, R63.2
unnamed: IC8.2, LK14.3
~Reset: LK3.1; also elsewhere on the board

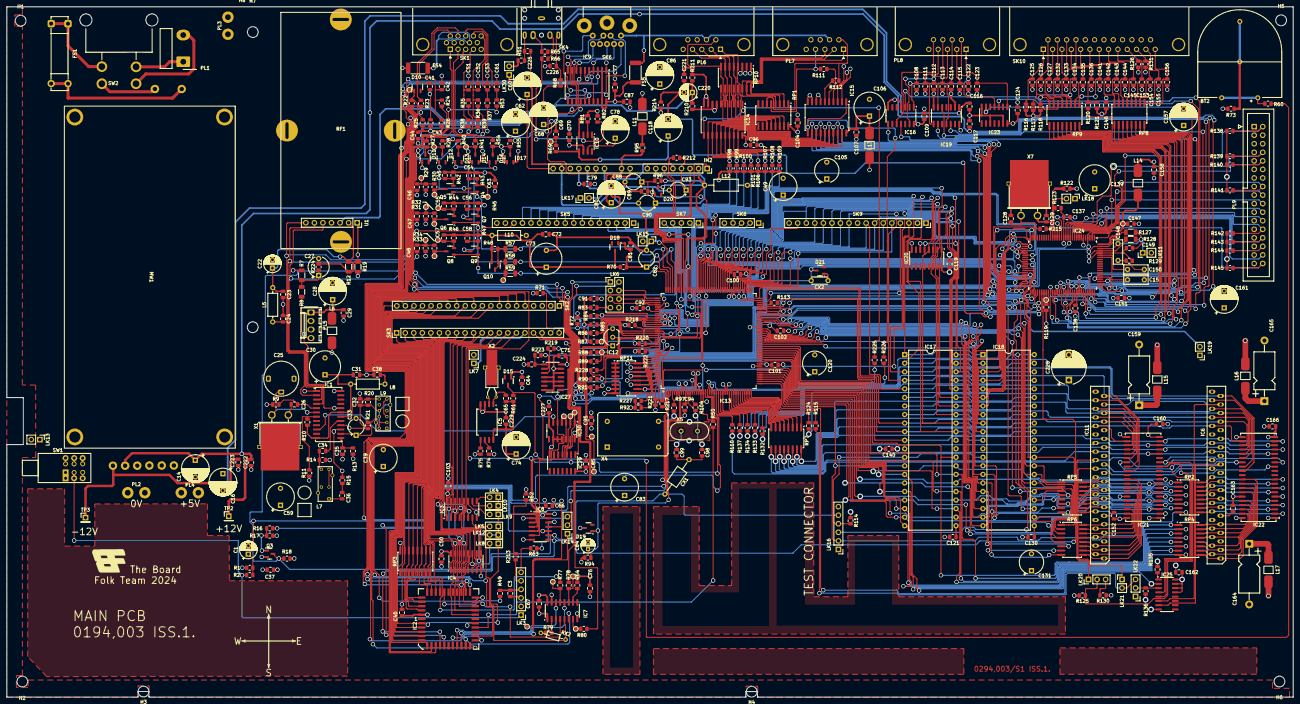
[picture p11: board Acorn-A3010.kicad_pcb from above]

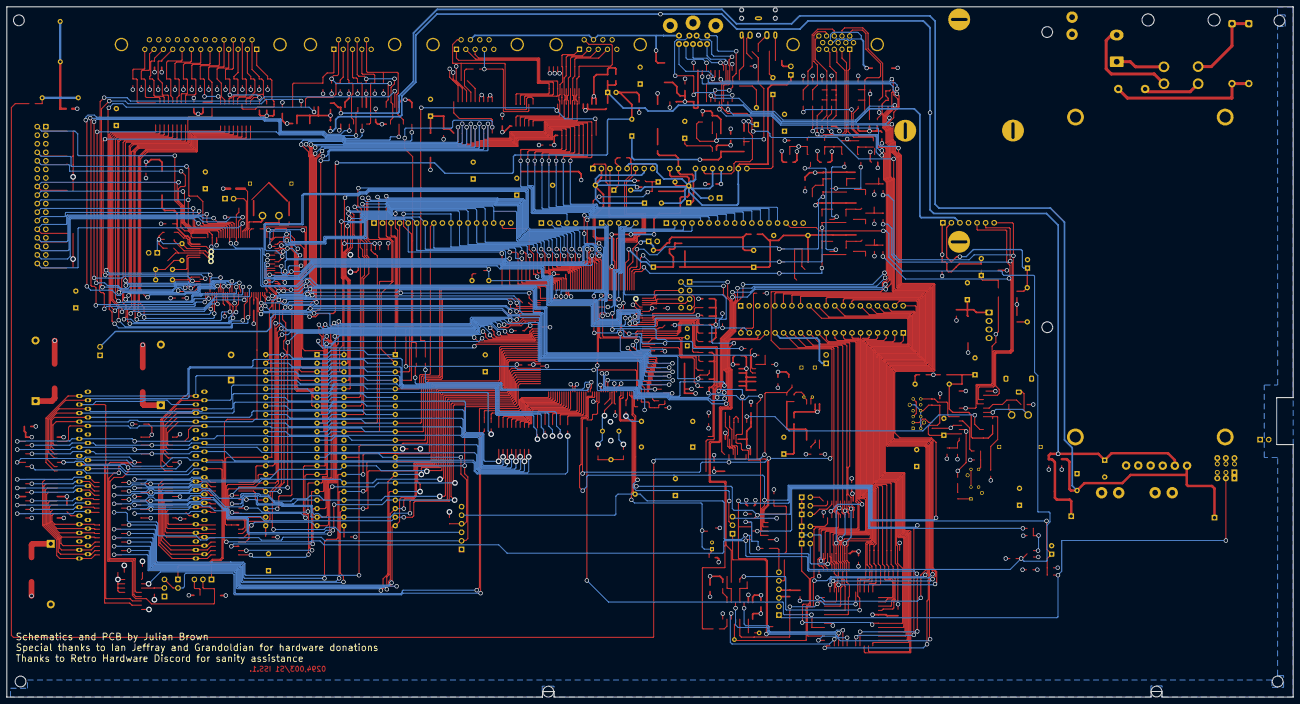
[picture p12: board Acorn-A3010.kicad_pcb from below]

Board: 4 copper layers, 382.0 x 205.0 mm, 480 parts (4 on the bottom side), 492 nets.

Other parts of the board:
Ge: LOGO; BoardFolk

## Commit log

2024-12-15 push initial work to git
    [Acorn-A3010.kicad_pcb, Acorn-A3010.kicad_sch, alt_keyboard.kicad_sch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]
2024-12-16 add io details
    [Acorn-A3010.kicad_pcb, cpu.kicad_sch, io.kicad_sch]
2024-12-17 extend io schematic
    [Acorn-A3010.kicad_pcb, io.kicad_sch]
2024-12-19 progress schematic
    [Acorn-A3010.kicad_pcb, Acorn-A3010.kicad_sch, audio.kicad_sch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]
2024-12-20 add vcc clean filter
    [Acorn-A3010.kicad_pcb, Acorn-A3010.kicad_sch, power.kicad_sch]
2024-12-21 add cheeky mean well power swap
    [Acorn-A3010.kicad_pcb, audio.kicad_sch, keyboard.kicad_sch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]
2024-12-21 fix port reference locations and lock components
    [Acorn-A3010.kicad_pcb, audio.kicad_sch, power.kicad_sch]
2024-12-22 fix perimter port positions
    [Acorn-A3010.kicad_pcb, Acorn-A3010.kicad_sch, audio.kicad_sch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]
2024-12-22 remove completely unnecessary -5V rail
    [Acorn-A3010.kicad_pcb, power.kicad_sch]
2024-12-22 work on io circuits
    [Acorn-A3010.kicad_pcb, io.kicad_sch]
2024-12-24 data path routing
    [Acorn-A3010.kicad_pcb, cpu.kicad_sch, power.kicad_sch]
2024-12-24 add digital video schematic
    [Acorn-A3010.kicad_pcb, cpu.kicad_sch, video.kicad_sch]
2024-12-25 add rf video output
    [Acorn-A3010.kicad_pcb, Acorn-A3010.kicad_sch, audio.kicad_sch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]
2024-12-27 more routing
    [Acorn-A3010.kicad_pcb, io.kicad_sch, power.kicad_sch]
2024-12-27 revise video layout
    [Acorn-A3010.kicad_pcb]
2024-12-28 wire in LA bus
    [Acorn-A3010.kicad_pcb, cpu.kicad_sch, power.kicad_sch]
2024-12-31 tracing refinement
    [Acorn-A3010.kicad_pcb, cpu.kicad_sch]
2025-01-02 implement video routing
    [Acorn-A3010.kicad_pcb, keyboard.kicad_sch, video.kicad_sch]
2025-01-03 video and keyboard routing
    [Acorn-A3010.kicad_pcb, audio.kicad_sch, keyboard.kicad_sch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]
2025-01-06 keyboard and joystick routing
    [Acorn-A3010.kicad_pcb, audio.kicad_sch, joysticks.kicad_sch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]
2025-01-06 fix rp11
    [Acorn-A3010.kicad_pcb, cpu.kicad_sch, joysticks.kicad_sch]
2025-01-08 more traces
    [Acorn-A3010.kicad_pcb, audio.kicad_sch, cpu.kicad_sch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]
2025-01-09 yet more traces
    [Acorn-A3010.kicad_pcb, alt_keyboard.kicad_sch, audio.kicad_sch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]
2025-01-10 keyboard routing
    [Acorn-A3010.kicad_pcb, audio.kicad_sch, cpu.kicad_sch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]
2025-01-15 progress power and keyboard
    [Acorn-A3010.kicad_pcb, keyboard.kicad_sch, power.kicad_sch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]
2025-01-15 analogue video
    [Acorn-A3010.kicad_pcb, tv.kicad_sch]
2025-01-17 more analogue video work
    [Acorn-A3010.kicad_pcb, cpu.kicad_sch, io.kicad_sch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]
2025-01-20 route out SW1 and SW2 traces
    [Acorn-A3010.kicad_pcb, keyboard.kicad_sch]
2025-01-20 sw trace routing
    [Acorn-A3010.kicad_pcb]
2025-01-21 last 20 traces to do
    [Acorn-A3010.kicad_pcb, audio.kicad_sch, cpu.kicad_sch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]
2025-01-24 all connections made - almost
    [Acorn-A3010.kicad_pcb]
2025-01-24 add missing capacitors
    [Acorn-A3010.kicad_pcb, power.kicad_sch, video.kicad_sch]
2025-01-25 prepare board for beta release
    [Acorn-A3010.kicad_pcb, reset.kicad_sch]
2025-02-01 Update design to remove the use of blind/buried vias to facilitate production
    [Acorn-A3010.kicad_pcb]
2025-02-23 correct ROM symbol
    [Acorn-A3010.kicad_pcb, rom.kicad_sch]
2025-03-05 fix footprint sizes
    [Acorn-A3010.kicad_pcb, audio.kicad_sch, keyboard.kicad_sch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]
2025-03-05 enlarge J-leg footprints
    [Acorn-A3010.kicad_pcb, keyboard.kicad_sch]
2025-03-05 board layout cosmetics
    [Acorn-A3010.kicad_pcb]
2025-03-07 adjust shielding perimeter trace and mounting holes
    [Acorn-A3010.kicad_pcb, audio.kicad_sch, cpu.kicad_sch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]
